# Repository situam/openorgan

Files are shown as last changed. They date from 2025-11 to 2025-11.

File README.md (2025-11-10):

# Open Organ

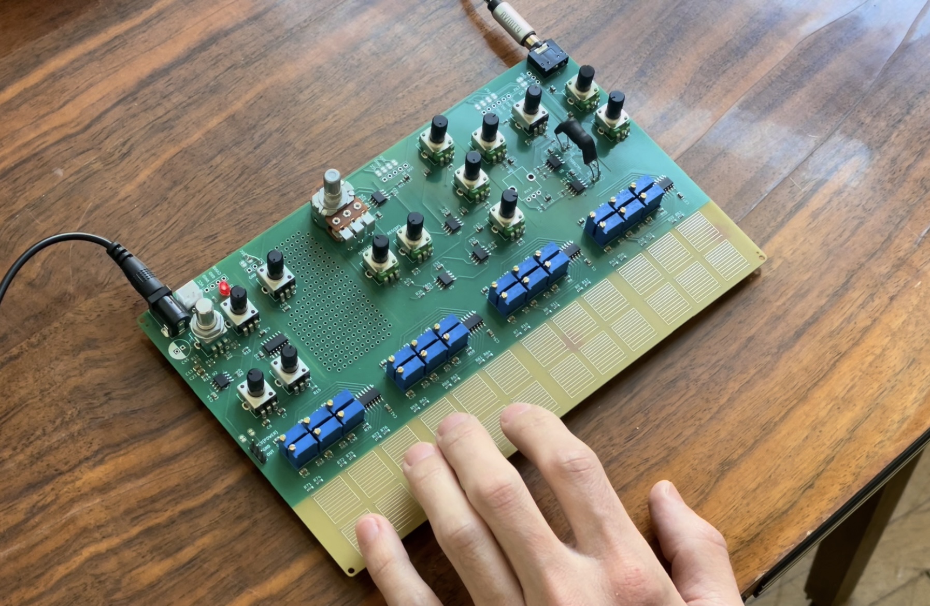
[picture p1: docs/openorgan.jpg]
open organ


A paraphonic analog synthesizer that offers tangible connections to its circuitry. Touch and moisture sensitive traces let the tunable voices flow into the shaping section. Filter, compressor, vibrato, and mixing modules are built in. Sound is also shaped by its power input, inviting musical interaction with the power source.

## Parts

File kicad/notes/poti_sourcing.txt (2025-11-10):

mouser stereo poti options
---

https://www.mouser.at/ProductDetail/Bourns/PTD902-1015K-B504?qs=%2FxQVPCMPNzj22d5HM%2FGT0Q%3D%3D

https://www.mouser.at/ProductDetail/Bourns/PDB182-K420K-504A?qs=g604JUmzuqvbczlAj9HJPA%3D%3D

https://www.mouser.at/ProductDetail/Bourns/PDB182-K420K-504A?qs=g604JUmzuqvbczlAj9HJPA%3D%3D

https://www.mouser.at/datasheet/2/54/PDB18-1013655.pdf

https://www.mouser.at/ProductDetail/Bourns/PDB182-K418F-105B?qs=2cAdsCoAWREzf3xvOlUM0Q%3D%3D

https://www.mouser.at/ProductDetail/Bourns/PDB182-D420K-503A?qs=h2IHEVivlqBUEPbrzurelQ%3D%3D

https://www.mouser.at/ProductDetail/Bourns/PDB182-D420K-503A?qs=h2IHEVivlqBUEPbrzurelQ%3D%3D

https://www.mouser.at/ProductDetail/Bourns/PDB182-K418F-105B?qs=2cAdsCoAWREzf3xvOlUM0Q%3D%3D

https://www.mouser.at/ProductDetail/Bourns/PDB182-K420K-504B?qs=g604JUmzuquwc%2Fv6HrgM%252Bg%3D%3D

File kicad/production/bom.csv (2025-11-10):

Designator | Footprint | Quantity | Value | LCSC Part #
C1, C27, C34, C41, C50, C51, C52, C53 | 0805 | 8 | 100nF
C10 | 0805 | 1 | 4.7uF
C11, C12 | 0805 | 2 | 10nF
C13, C14, C22, C24, C25 | 0805 | 5 | 0.1uF
C15, C16, C17, C18, C19, C20, C21, C23, C7, C9 | 0805 | 10 | 10uF
C2, C26, C28, C29, C3, C30, C31, C32, C33, C35, C36, C37, C38, C39, C4, C40, C42, C43, C44, C46, C47, C48, C5, C6 | 0805 | 24 | 0.47uF
C49 | 0805 | 1 | 10-100nF
C8 | 0805 | 1 | 1uF
R1, R10, R11, R12, R15, R2, R23, R24, R25, R26, R3, R4, R40, R41, R42, R43, R44, R45, R46, R47, R48, R49, R5, R50, R51, R52, R53, R54, R55, R56, R57, R58, R59, R6, R60, R61, R62, R63, R64, R65, R66, R67, R68, R69, R7, R70, R71, R72, R73, R74, R75, R76, R77, R78, R8, R9 | 0603 | 56 | 1K
R13, R14, R18, R19, R20, R27, R28, R29, R30, R34 | 0603 | 10 | 100K
R16, R17, R31, R32, R33, R37, R38, R39 | 0603 | 8 | 10K
R21 | 0603 | 1 | 47R
R22 | 0603 | 1 | 22K
R35 | 0603 | 1 | 33K
R79 | 0603 | 1 | 4.7K
RV1, RV2, RV21, RV22, RV23, RV24, RV25, RV26, RV27, RV28, RV29, RV3, RV30, RV31, RV32, RV33, RV34, RV35, RV36, RV37, RV38, RV4, RV5, RV6 | Potentiometer_Bourns_3296W_Vertical | 24 | 100K | C118963
U1, U10, U11, U12, U3 | SOIC-14_L8.7-W3.9-P1.27-LS6.0-BL | 5 | 40106 | C38184
U2 | SOIC-8_L5.0-W4.0-P1.27-LS6.0-BL | 1 | LM358 | C7950
U4, U5, U6, U7, U8, U9 | SOIC-8_L4.9-W3.9-P1.27-LS6.0-BL | 6 | NE5532 | C7426

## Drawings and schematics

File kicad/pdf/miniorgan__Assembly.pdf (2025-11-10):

A

A

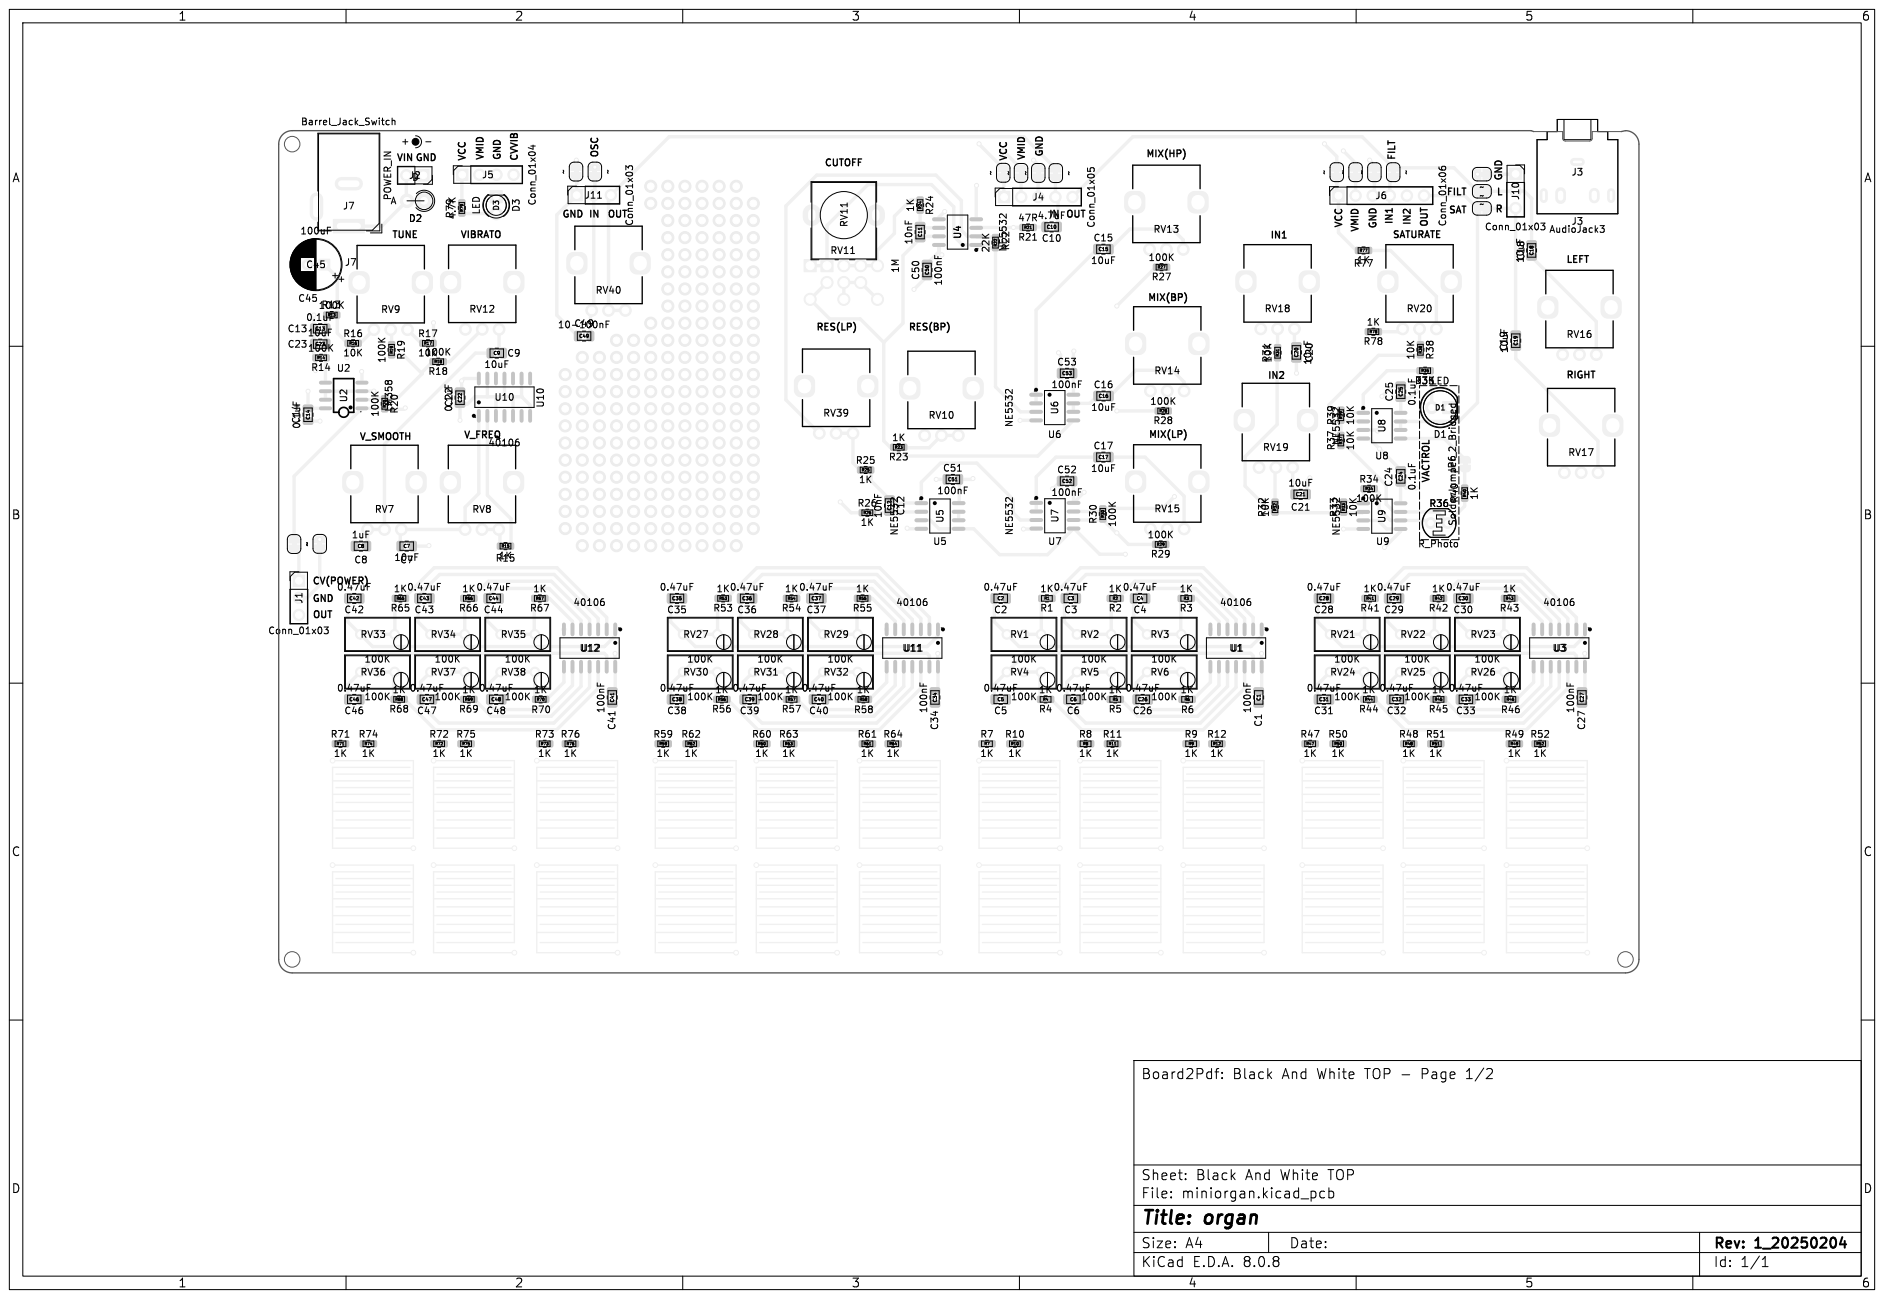
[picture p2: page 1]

File: miniorgan.kicad_pcb Sheet: Black And White TOP
Id: 1/1 Title: organ

A

A

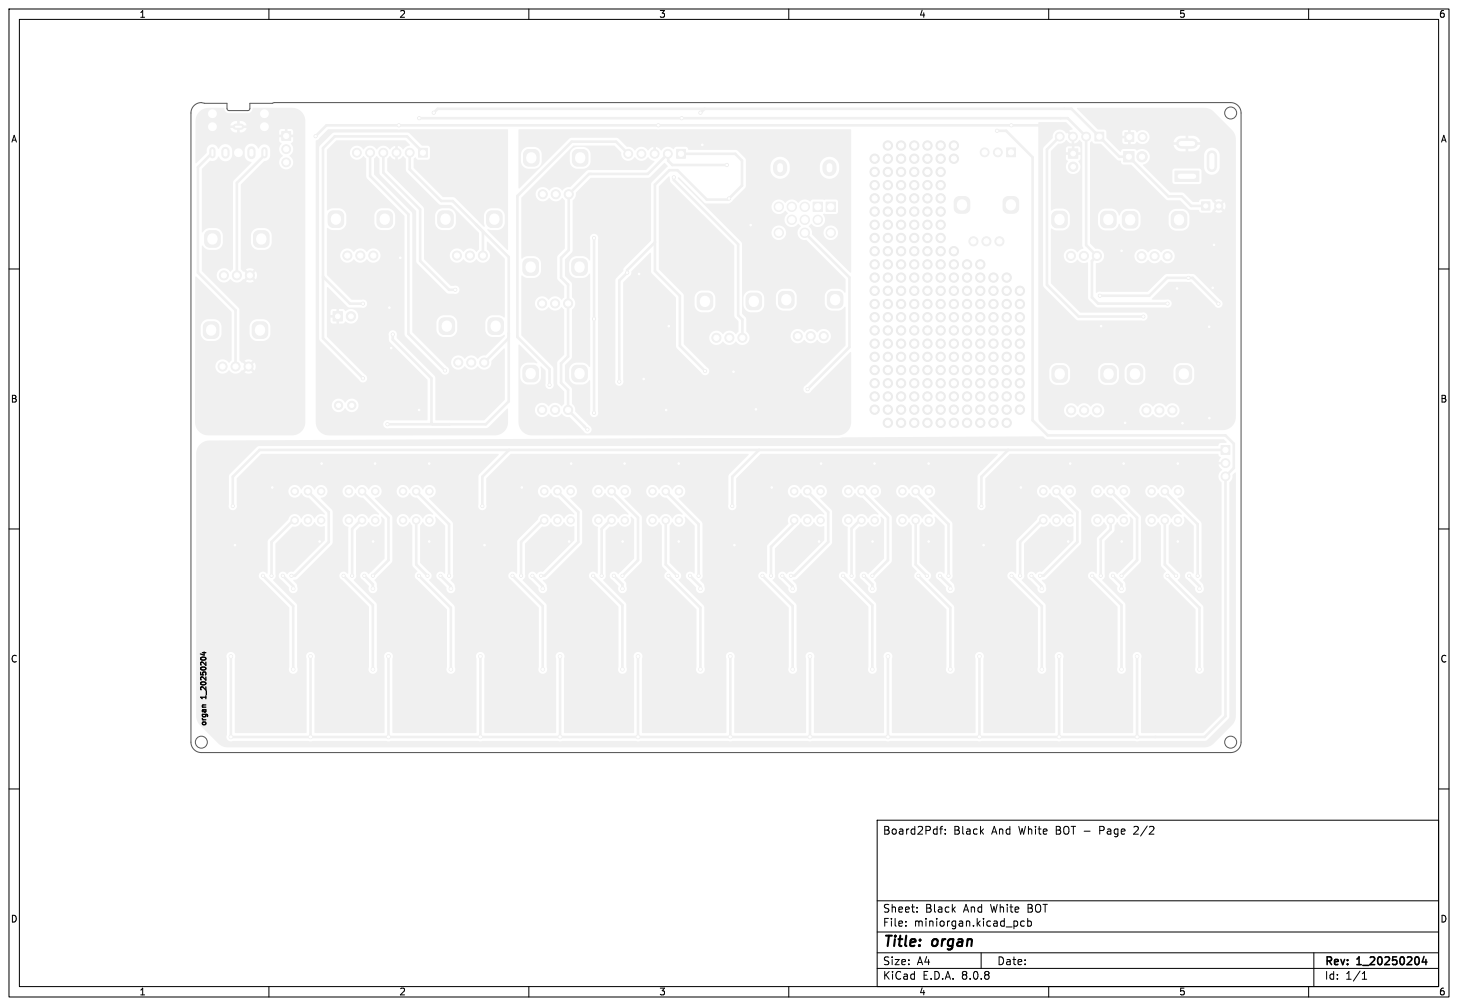
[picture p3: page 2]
organ 1_20250204 1 2 3 4 5 6; D Date: KiCad; E.D.A. 8.0.8 Size: A4; Rev: 1_20250204; File: miniorgan.kicad_pcb Sheet: Black; And; White; BOT Board2Pdf:; Black; BOT -; Page 2/2

Id: 1/1 Title: organ

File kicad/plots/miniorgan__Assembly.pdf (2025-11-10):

A

A

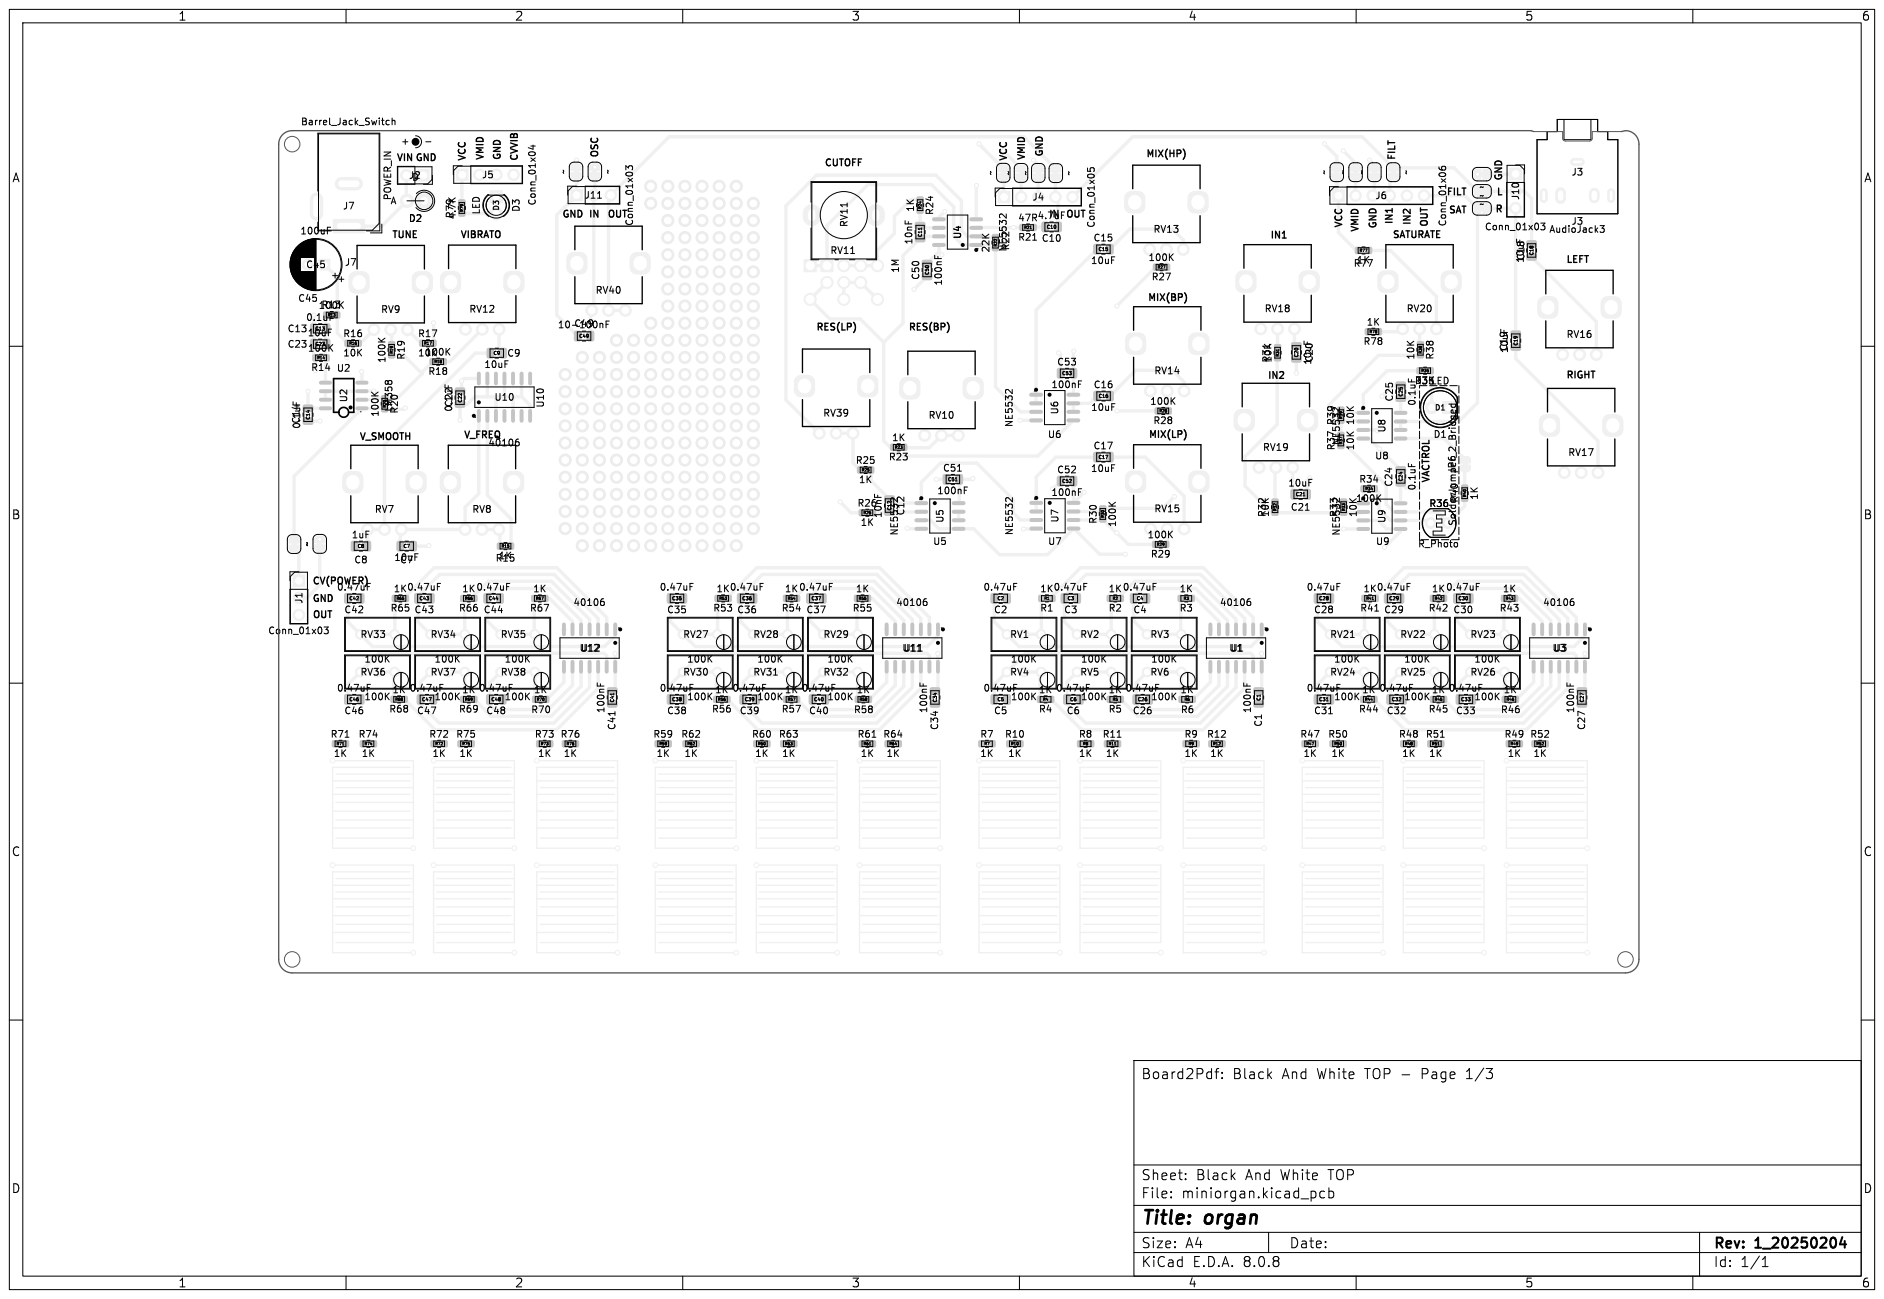
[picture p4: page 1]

File: miniorgan.kicad_pcb Sheet: Black And White TOP
Id: 1/1 Title: organ

A

A

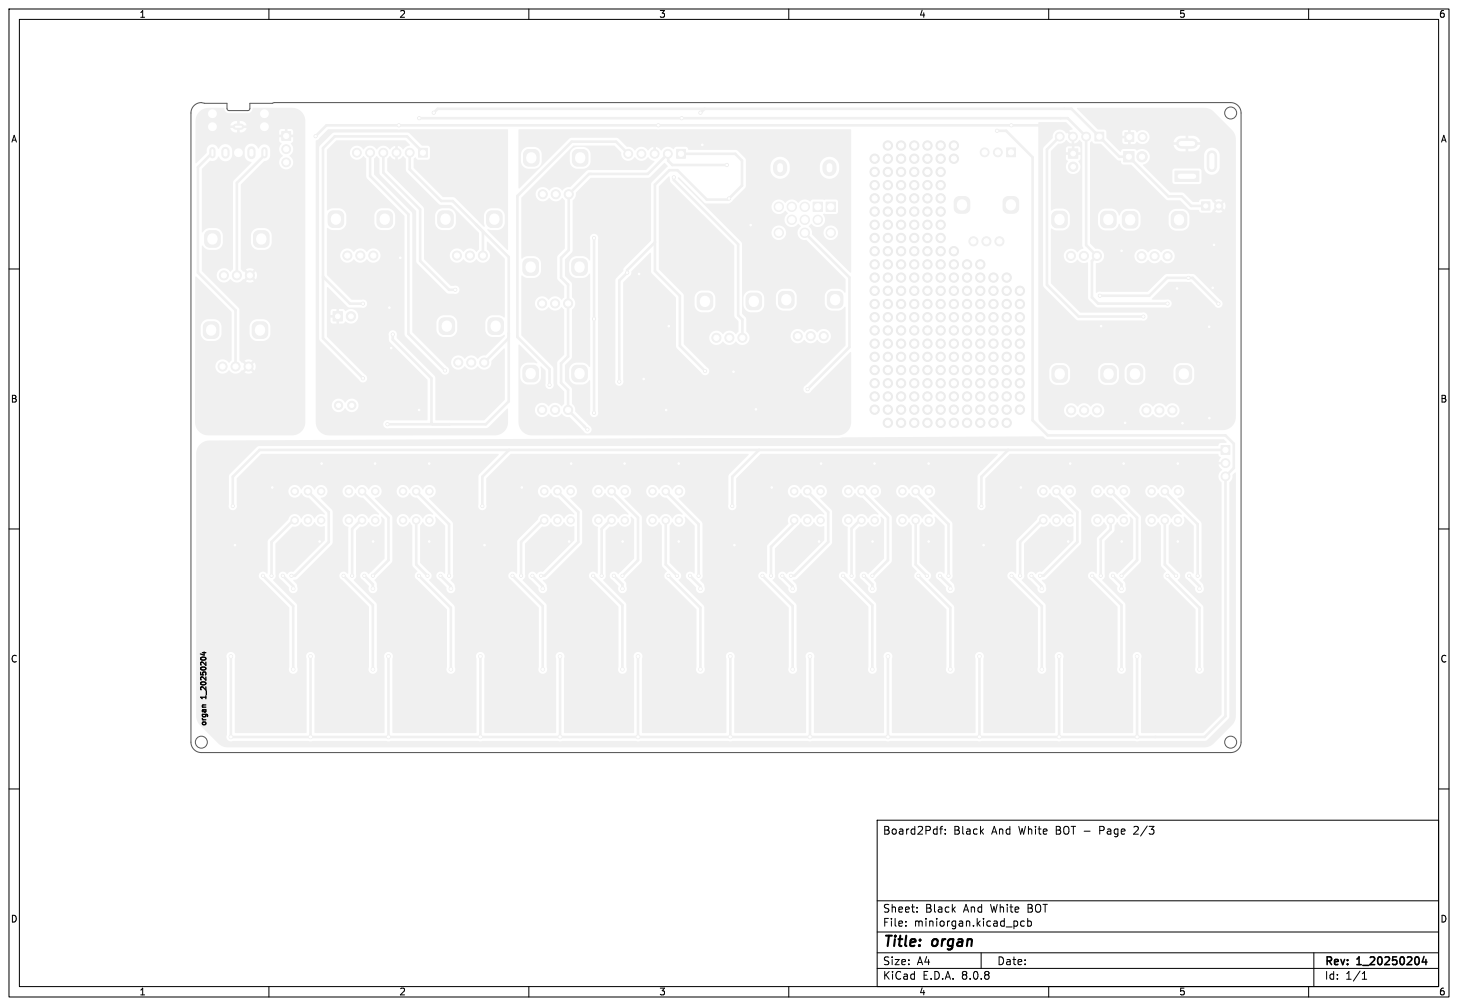
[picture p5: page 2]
organ 1_20250204 1 2 3 4 5 6; D Date: KiCad; E.D.A. 8.0.8 Size: A4; Rev: 1_20250204; File: miniorgan.kicad_pcb Sheet: Black; And; White; BOT Board2Pdf:; Black; BOT -; Page 2/3

Id: 1/1 Title: organ

A

A

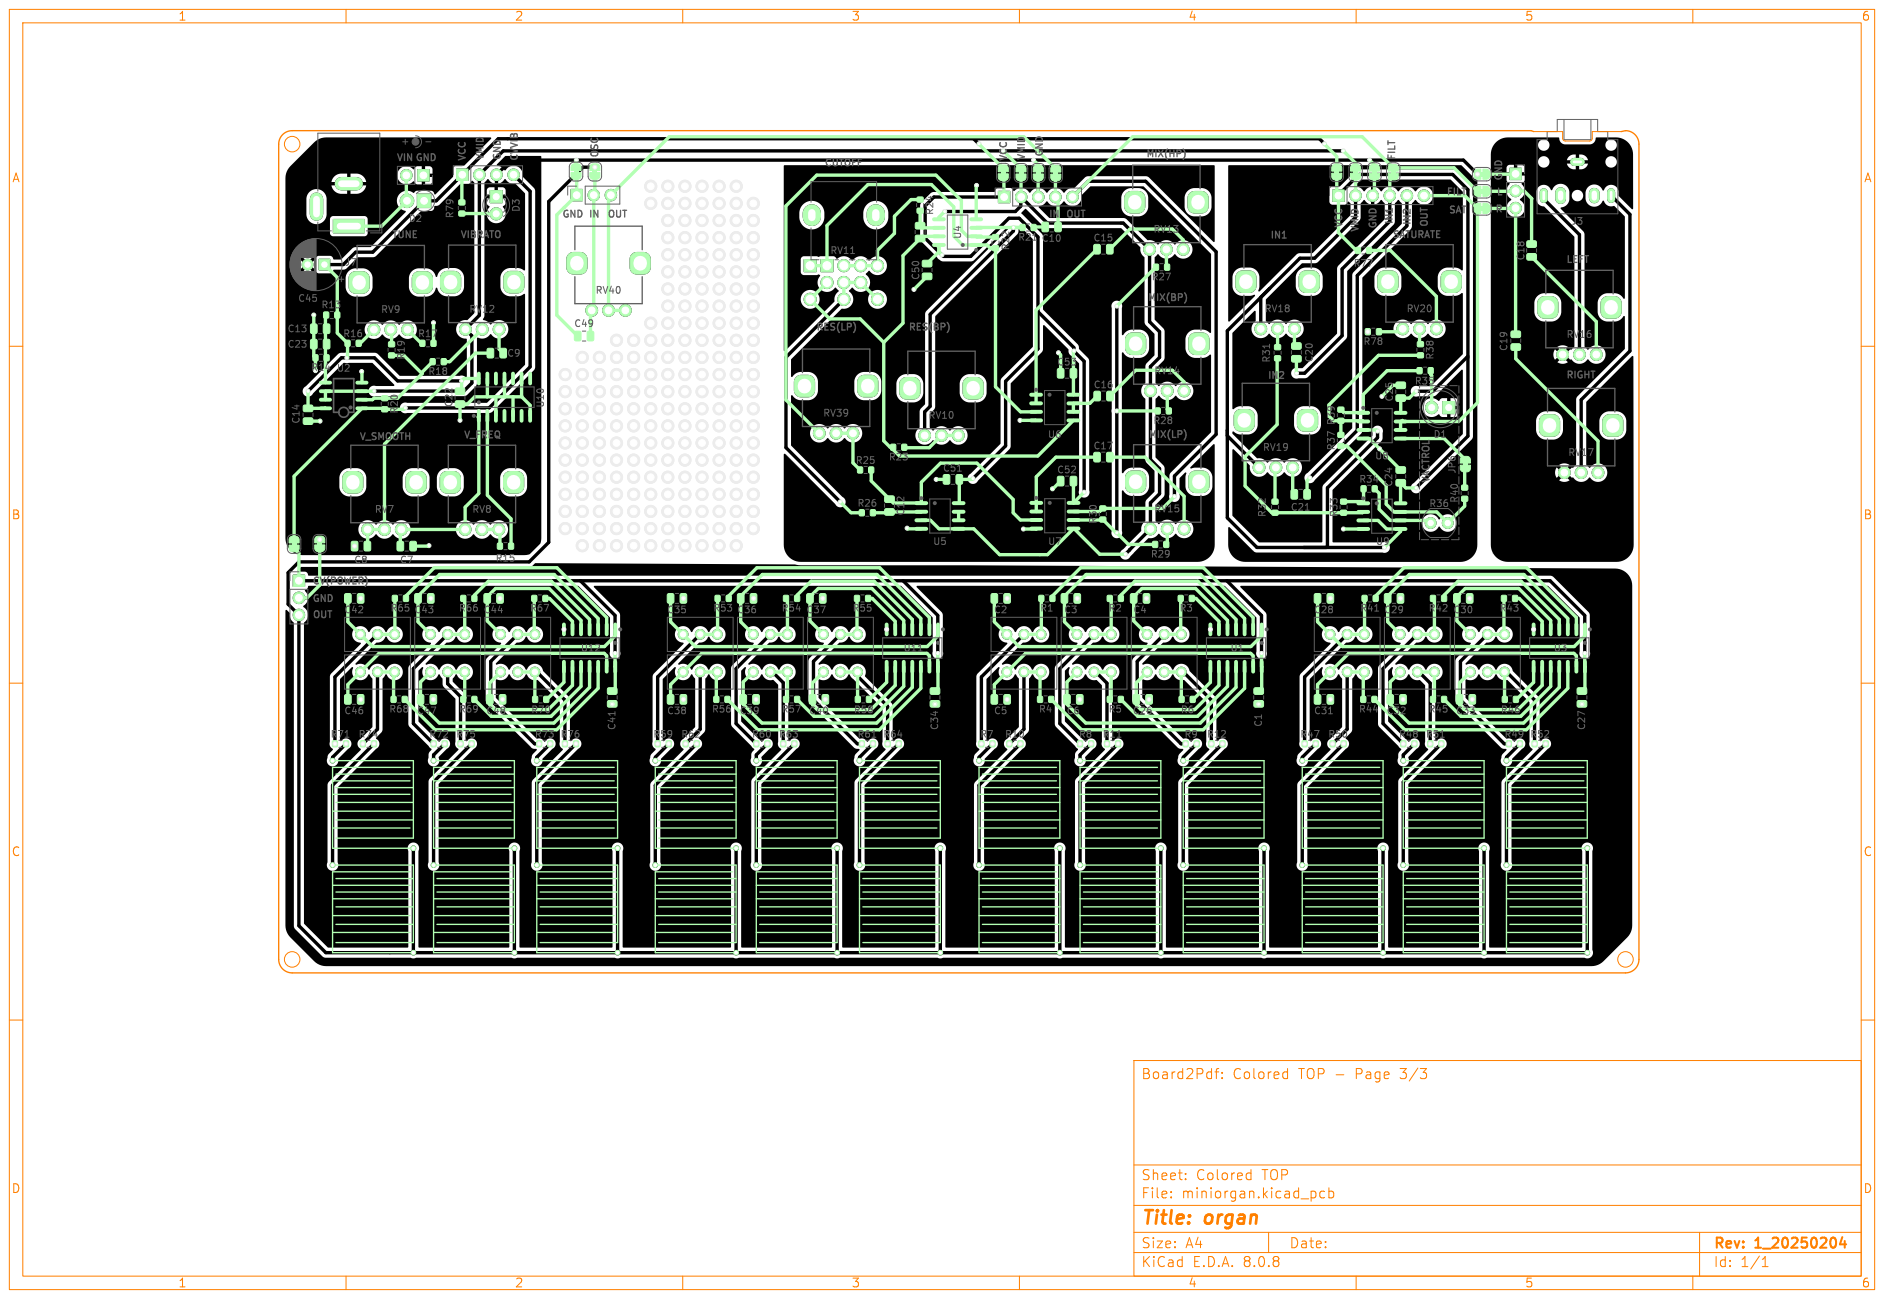
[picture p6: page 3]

File: miniorgan.kicad_pcb Sheet: Colored TOP
Id: 1/1 Title: organ

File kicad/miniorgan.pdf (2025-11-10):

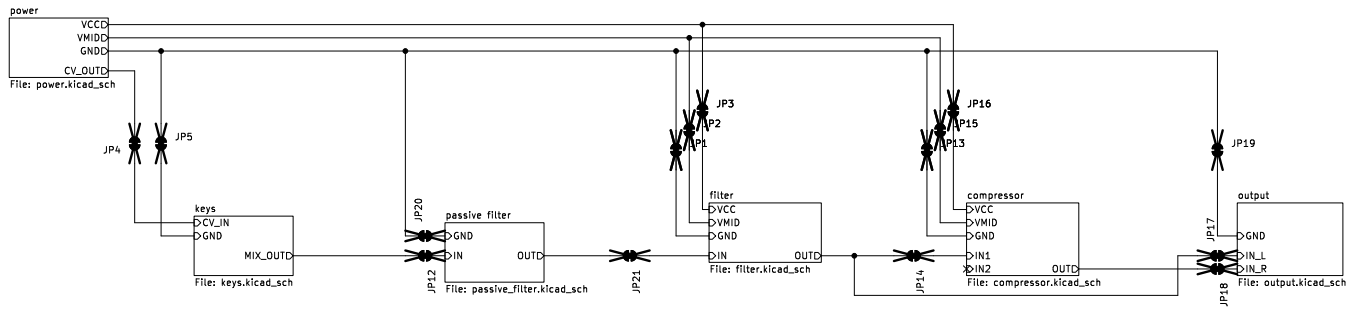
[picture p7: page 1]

VCC
CV_OUT VMID
filter File: filter.kicad_sch GND

compressor File: compressor.kicad_sch MIX_OUT GND
keys File: keys.kicad_sch

output File: output.kicad_sch VMID

File: miniorgan.kicad_sch Sheet: /
Id: 1/11 Title: Open Organ

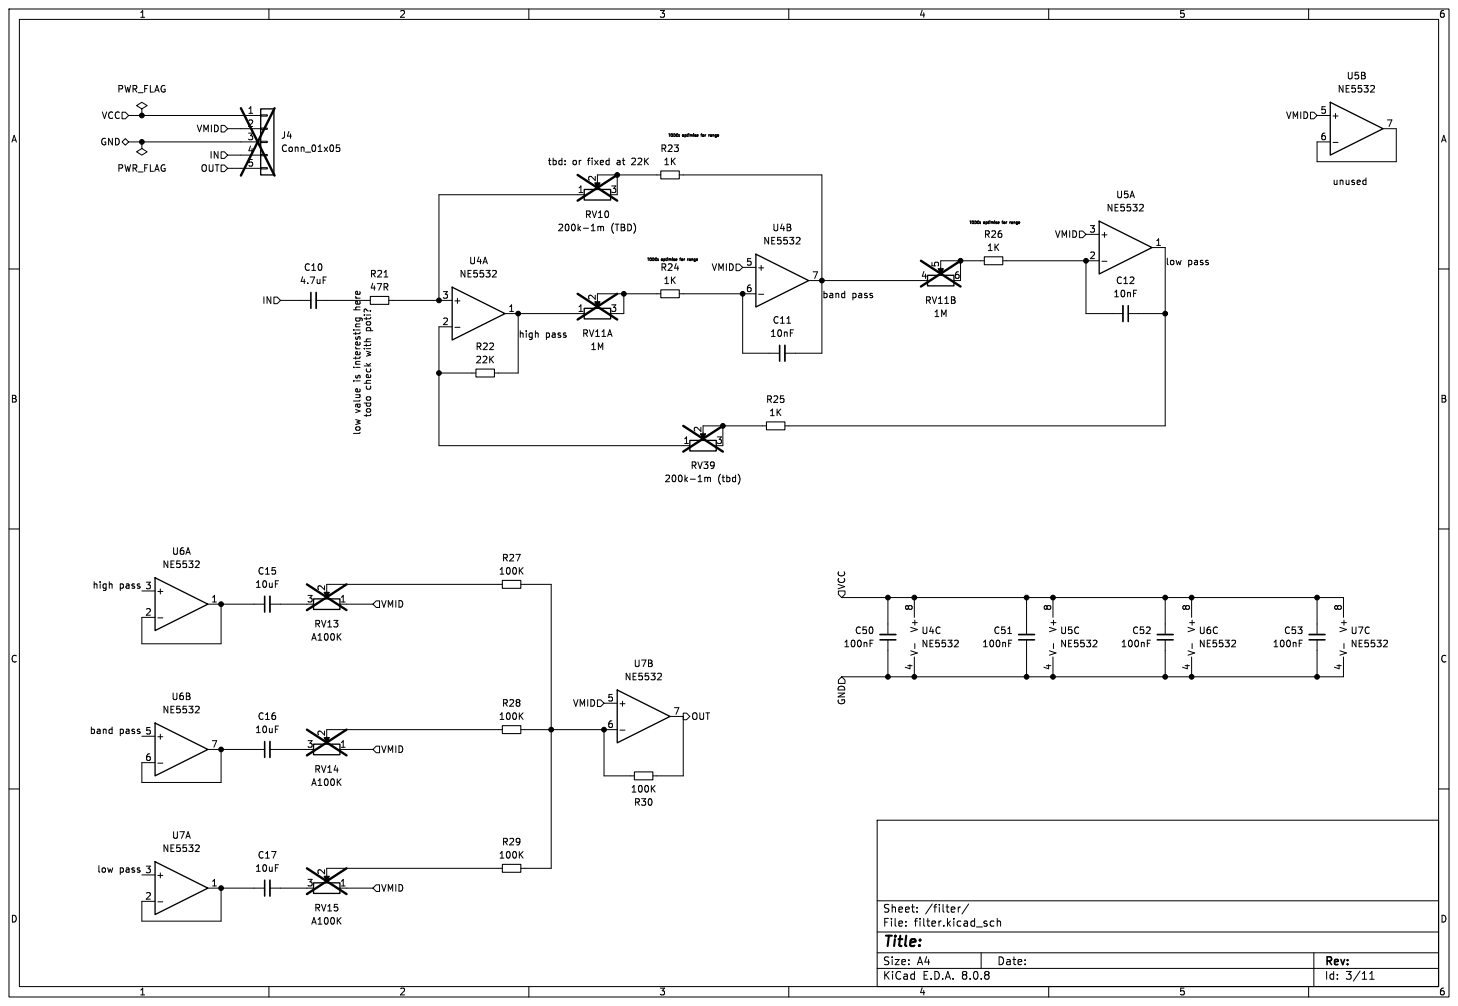
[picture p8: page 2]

Id: 3/11 Title: File: filter.kicad_sch Sheet: /filter/ +

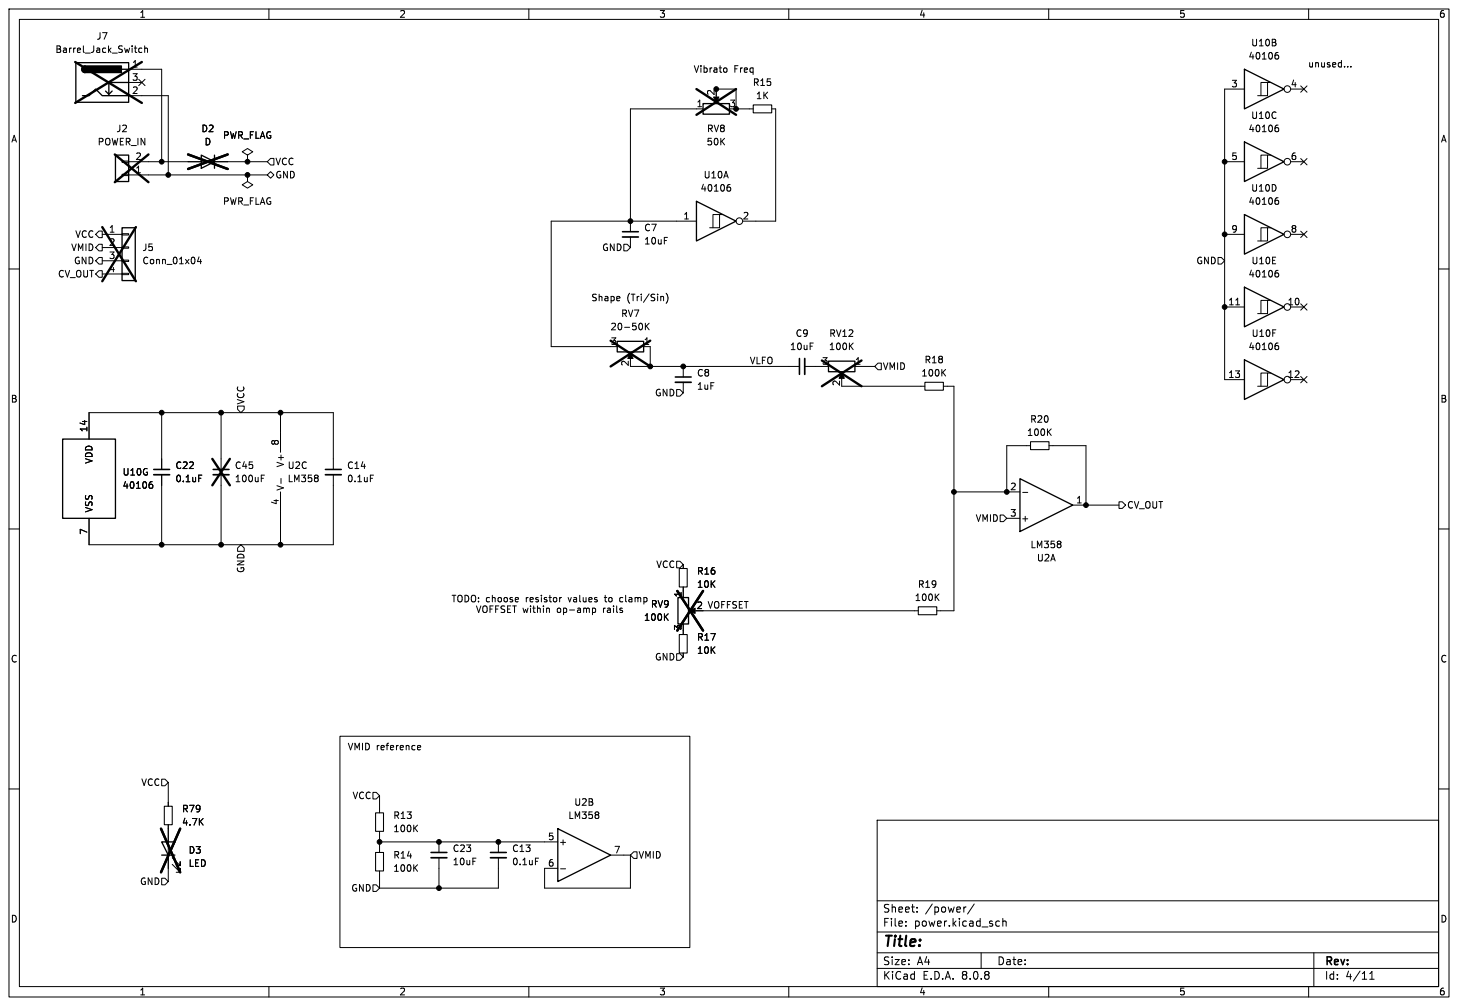
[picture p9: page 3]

Id: 4/11 Title: File: power.kicad_sch Sheet: /power/

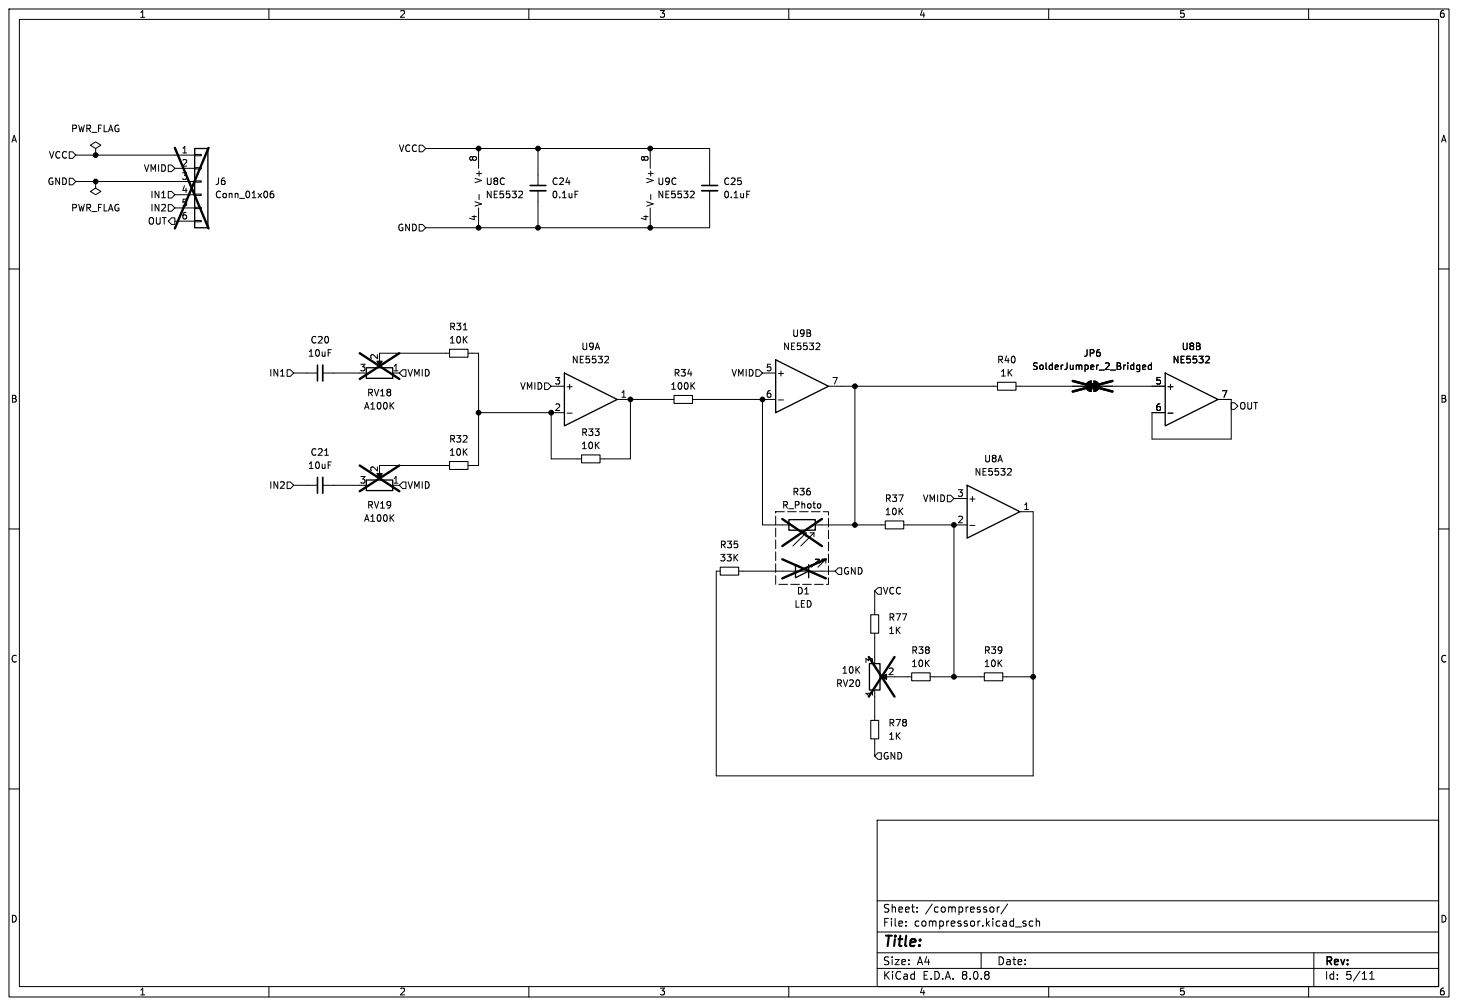
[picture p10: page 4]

Id: 5/11 Title: File: compressor.kicad_sch Sheet: /compressor/ R78

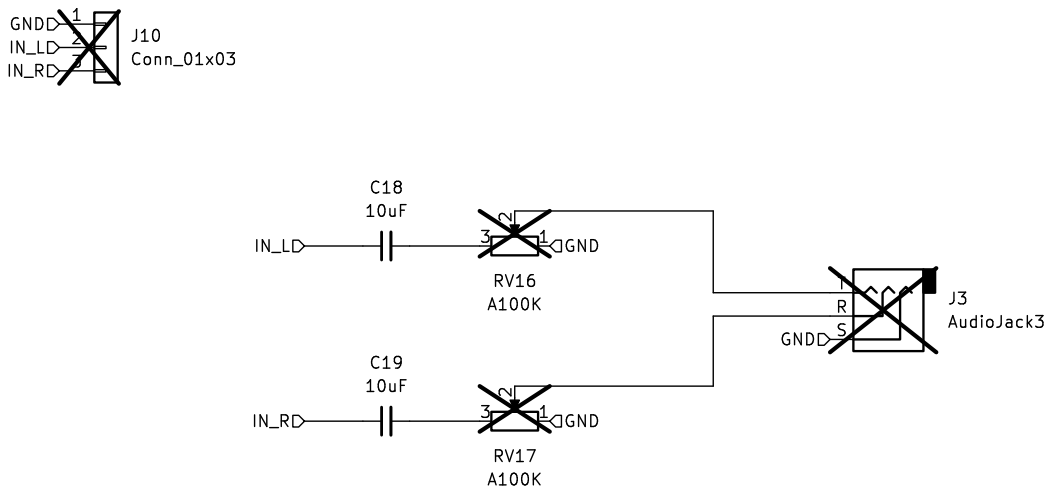
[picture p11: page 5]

Id: 7/11 Title: File: output.kicad_sch Sheet: /output/

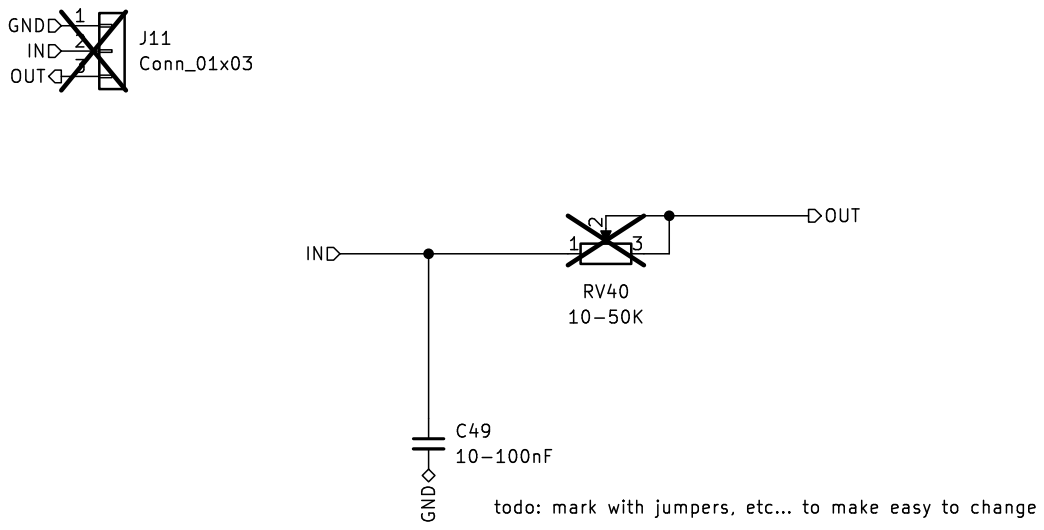
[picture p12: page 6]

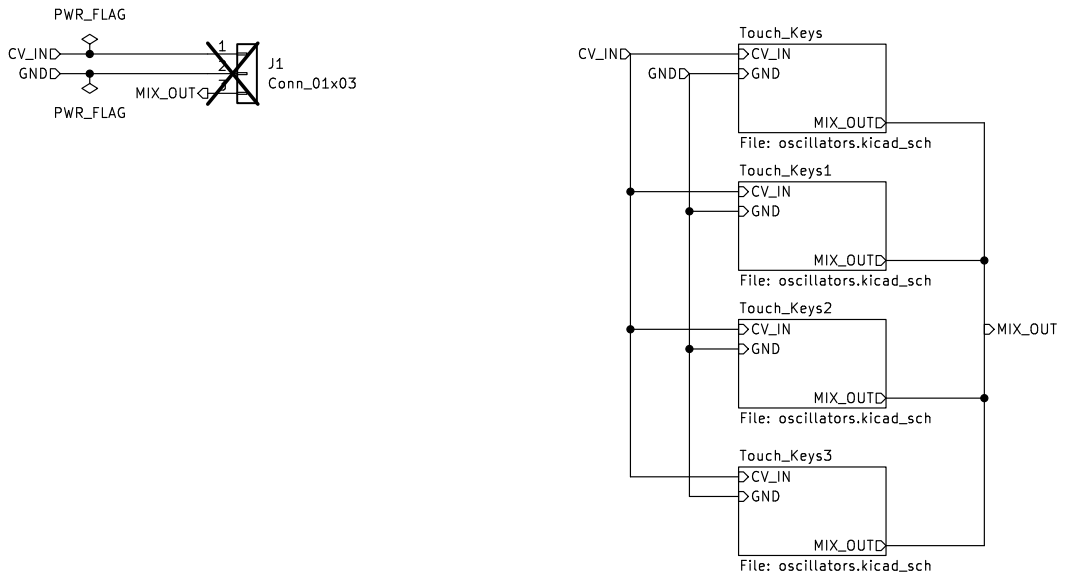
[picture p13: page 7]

Id: 11/11 Title: File: keys.kicad_sch Sheet: /keys/ MIX_OUT CV_IN GND


Id: 12/11 Title: File: oscillators.kicad_sch Sheet: /keys/Touch_Keys/ R6


Id: 13/11 Title: File: oscillators.kicad_sch Sheet: /keys/Touch_Keys1/ R46


Id: 14/11 Title: File: oscillators.kicad_sch Sheet: /keys/Touch_Keys2/ R58


Id: 15/11 Title: File: oscillators.kicad_sch Sheet: /keys/Touch_Keys3/ R70

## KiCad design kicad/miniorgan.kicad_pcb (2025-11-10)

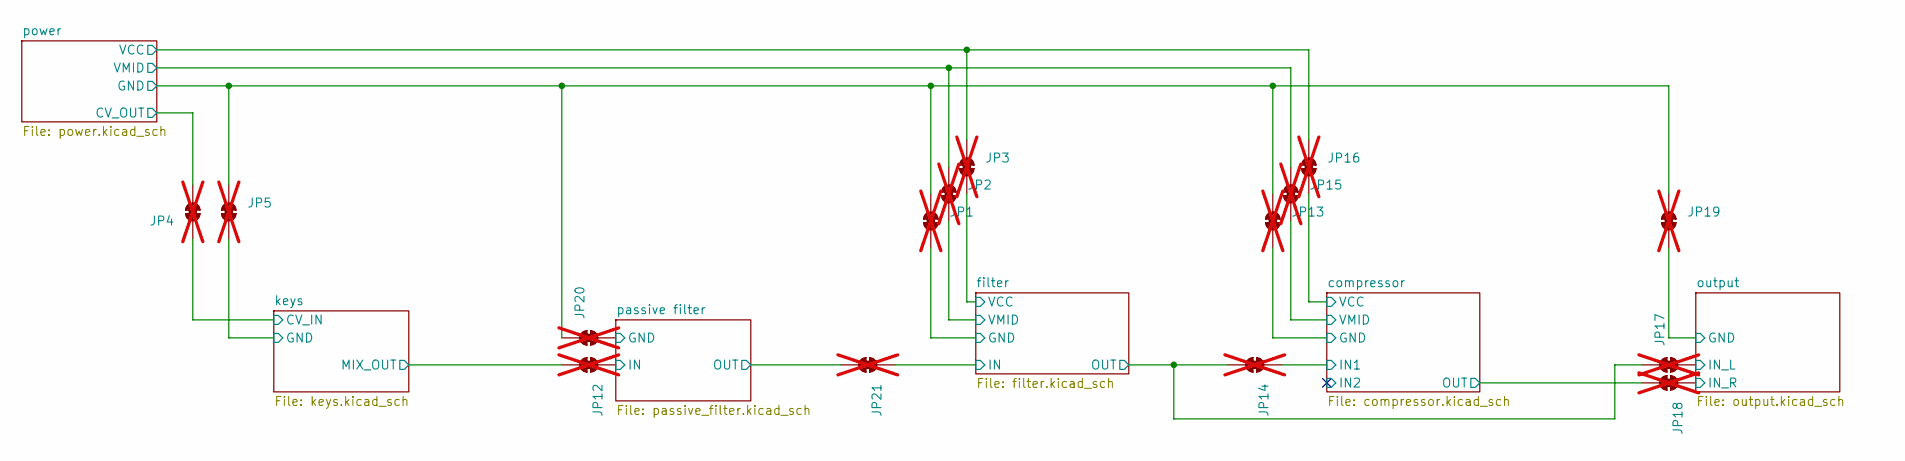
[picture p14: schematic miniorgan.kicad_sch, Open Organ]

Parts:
JP1, JP2, JP3, JP4, JP5, JP12, JP13, JP14, JP15, JP16, JP17, JP18, JP19, JP20, JP21: SolderJumper-2_P1.3mm_Bridged_RoundedPad1.0x1.5mm; not fitted

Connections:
/Filter/GND: JP1.2 (B); also elsewhere on the board
/Filter/IN: JP21.1 (A); also elsewhere on the board
/Filter/OUT: JP14.2 (B), JP17.1 (A); also elsewhere on the board
/Filter/VCC: JP3.2 (B); also elsewhere on the board
/Filter/VMID: JP2.2 (B); also elsewhere on the board
/keys/CV_IN: JP4.1 (A); also elsewhere on the board
/keys/GND: JP5.2 (B); also elsewhere on the board
/keys/MIX_OUT: JP12.2 (B); also elsewhere on the board
/output/GND: JP19.2 (B); also elsewhere on the board
/output/IN_L: JP17.2 (B); also elsewhere on the board
/output/IN_R: JP18.1 (A); also elsewhere on the board
/passive filter/GND: JP20.2 (B); also elsewhere on the board
/passive filter/IN: JP12.1 (A); also elsewhere on the board
/passive filter/OUT: JP21.2 (B); also elsewhere on the board
/power/CV_OUT: JP4.2 (B); also elsewhere on the board
/power/GND: JP1.1 (A), JP5.1 (A), JP13.1 (A), JP19.1 (A), JP20.1 (A); also elsewhere on the board
/power/VCC: JP3.1 (A), JP16.1 (A); also elsewhere on the board
/power/VMID: JP2.1 (A), JP15.1 (A); also elsewhere on the board
/vactrol compressor/GND: JP13.2 (B); also elsewhere on the board
/vactrol compressor/IN1: JP14.1 (A); also elsewhere on the board
/vactrol compressor/OUT: JP18.2 (B); also elsewhere on the board
/vactrol compressor/VCC: JP16.2 (B); also elsewhere on the board
/vactrol compressor/VMID: JP15.2 (B); also elsewhere on the board

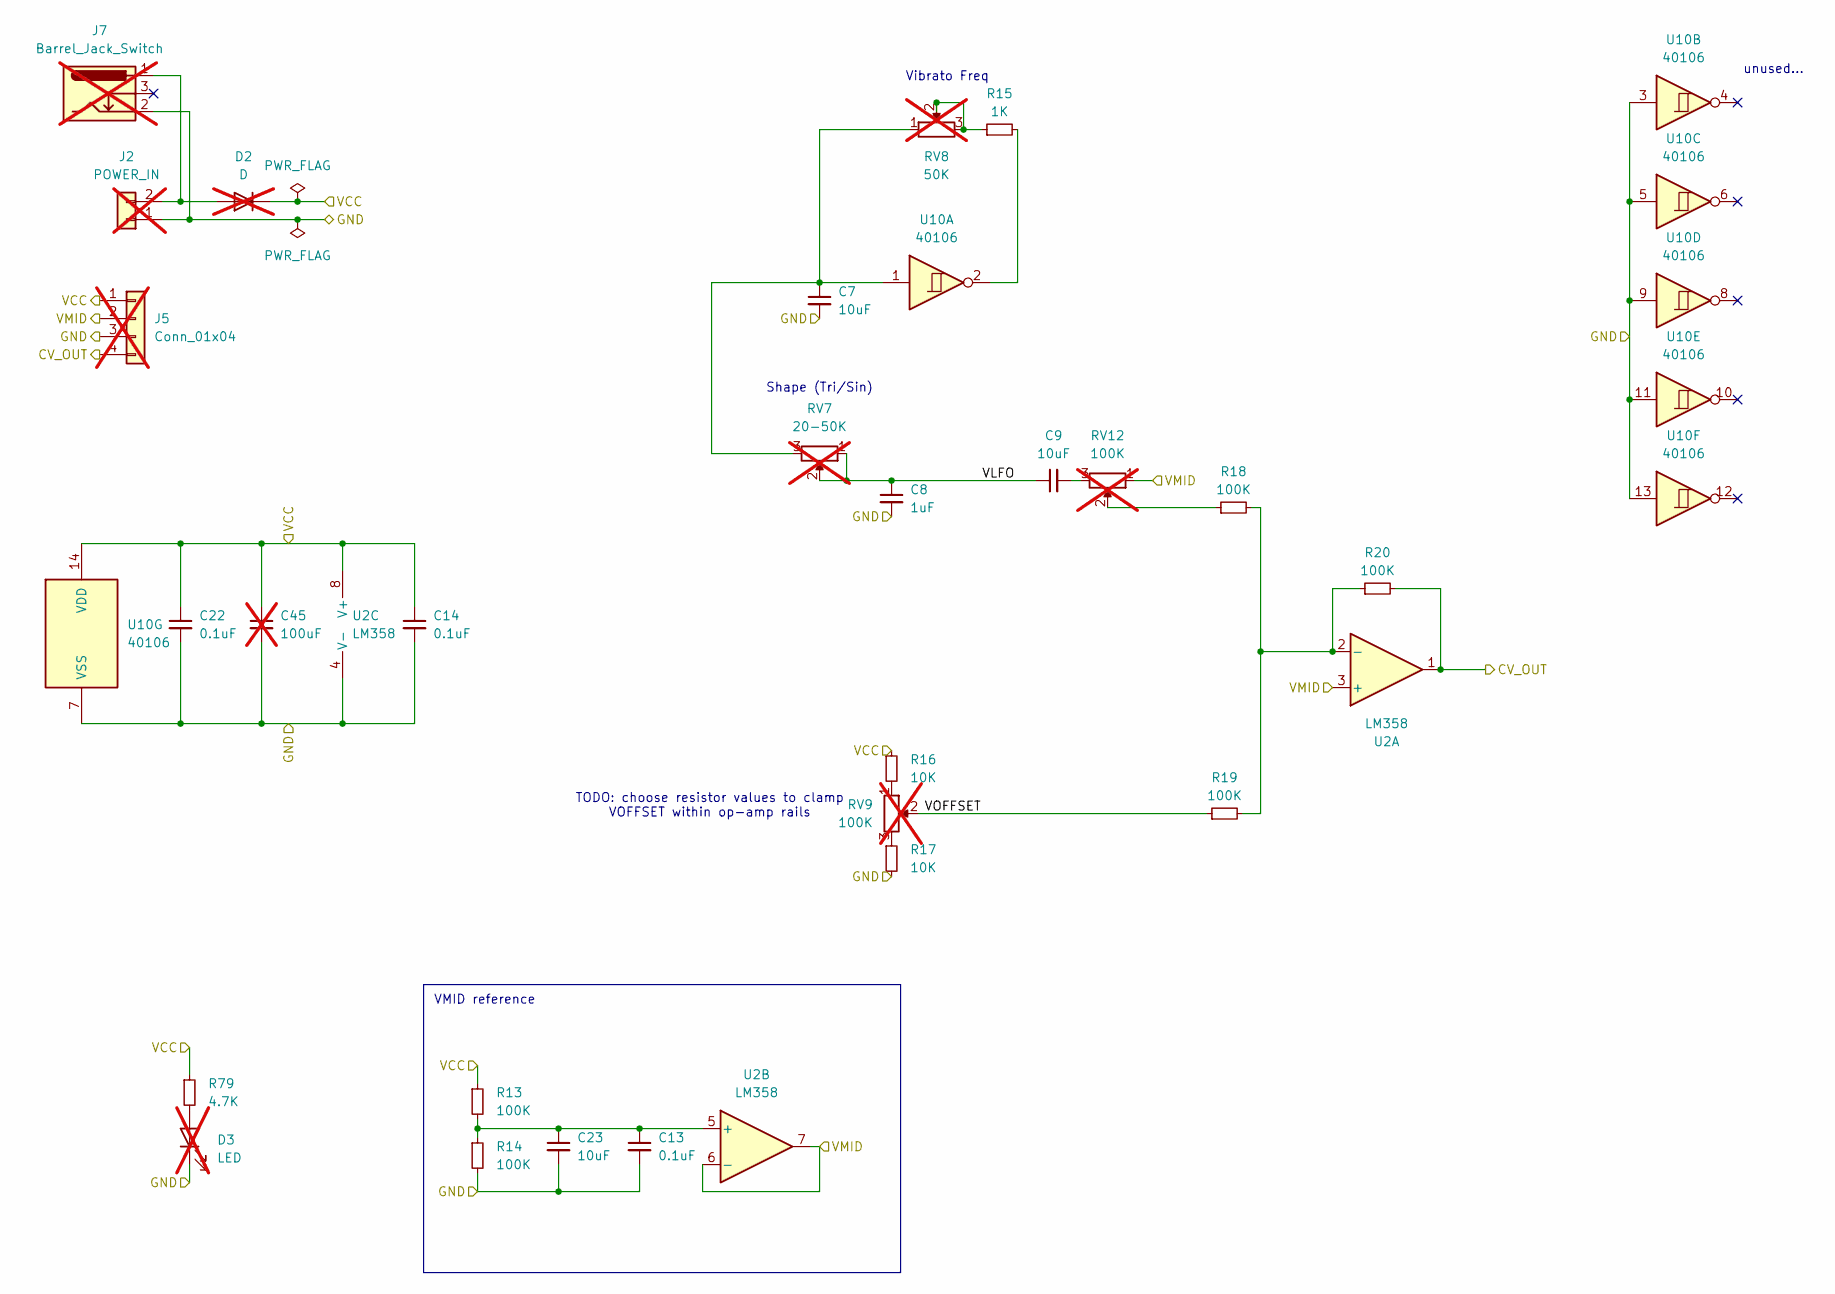
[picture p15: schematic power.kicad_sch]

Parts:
C7, C9, C23: 10uF; C_0805_2012Metric
C8: 1uF; C_0805_2012Metric
C13, C14, C22: 0.1uF; C_0805_2012Metric
C45: 100uF; CP_Radial_D7.5mm_P2.50mm; not fitted
D2: D; D_T-1_P2.54mm_Vertical_AnodeUp; not fitted
D3: LED; LED_D3.0mm; not fitted
J2: POWER_IN; PinSocket_1x02_P2.54mm_Vertical; not fitted
J5: Conn_01x04; PinSocket_1x04_P2.54mm_Vertical; not fitted
J7: Barrel_Jack_Switch; BarrelJack_GCT_DCJ200-10-A_Horizontal; not fitted
R13, R14, R18, R19, R20: 100K; R_0603_1608Metric
R15: 1K; R_0603_1608Metric
R16, R17: 10K; R_0603_1608Metric
R79: 4.7K; R_0603_1608Metric
RV7: 20-50K; Pot_RV09AF-ALPHA; not fitted
RV8: 50K; Pot_RV09AF-ALPHA; not fitted
RV9, RV12: 100K; Pot_RV09AF-ALPHA; not fitted
U2: LM358; SOIC-8_L5.0-W4.0-P1.27-LS6.0-BL; JLC C7950
U10: 40106; SOIC-14_L8.7-W3.9-P1.27-LS6.0-BL; JLC C38184

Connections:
/power/CV_OUT: J5.4, R20.2, U2.1; also elsewhere on the board
/power/GND: C7.2, C8.2, C13.2, C14.2, C22.2, C23.2, C45.2, D3.1 (K), J2.1, J5.3, J7.2, R14.2, R17.2, U2.4 (V-), U10.3, U10.5, U10.7 (VSS), U10.9, U10.11, U10.13; also elsewhere on the board
/power/VCC: C14.1, C22.1, C45.1, D2.1 (K), J5.1, R13.1, R16.1, R79.1, U2.8 (V+), U10.14 (VDD); also elsewhere on the board
/power/VLFO: C8.1, C9.1, RV7.1, RV7.2
/power/VMID: J5.2, RV12.1, U2.3 (+), U2.6 (-), U2.7; also elsewhere on the board
/power/VOFFSET: R19.1, RV9.2
unnamed: C7.1, RV7.3, RV8.1, U10.1
unnamed: C9.2, RV12.3
unnamed: D2.2 (A), J2.2, J7.1
unnamed: D3.2 (A), R79.2
unnamed: R15.1, RV8.2, RV8.3
unnamed: R15.2, U10.2
unnamed: R16.2, RV9.1
unnamed: R17.1, RV9.3
unnamed: R18.1, RV12.2
unnamed: R18.2, R19.2, R20.1, U2.2 (-)
unnamed: C13.1, C23.1, R13.2, R14.1, U2.5 (+)

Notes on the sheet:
TODO: choose resistor values to clamp VOFFSET within op-amp rails
Vibrato Freq
Shape (Tri/Sin)
VMID reference
unused...

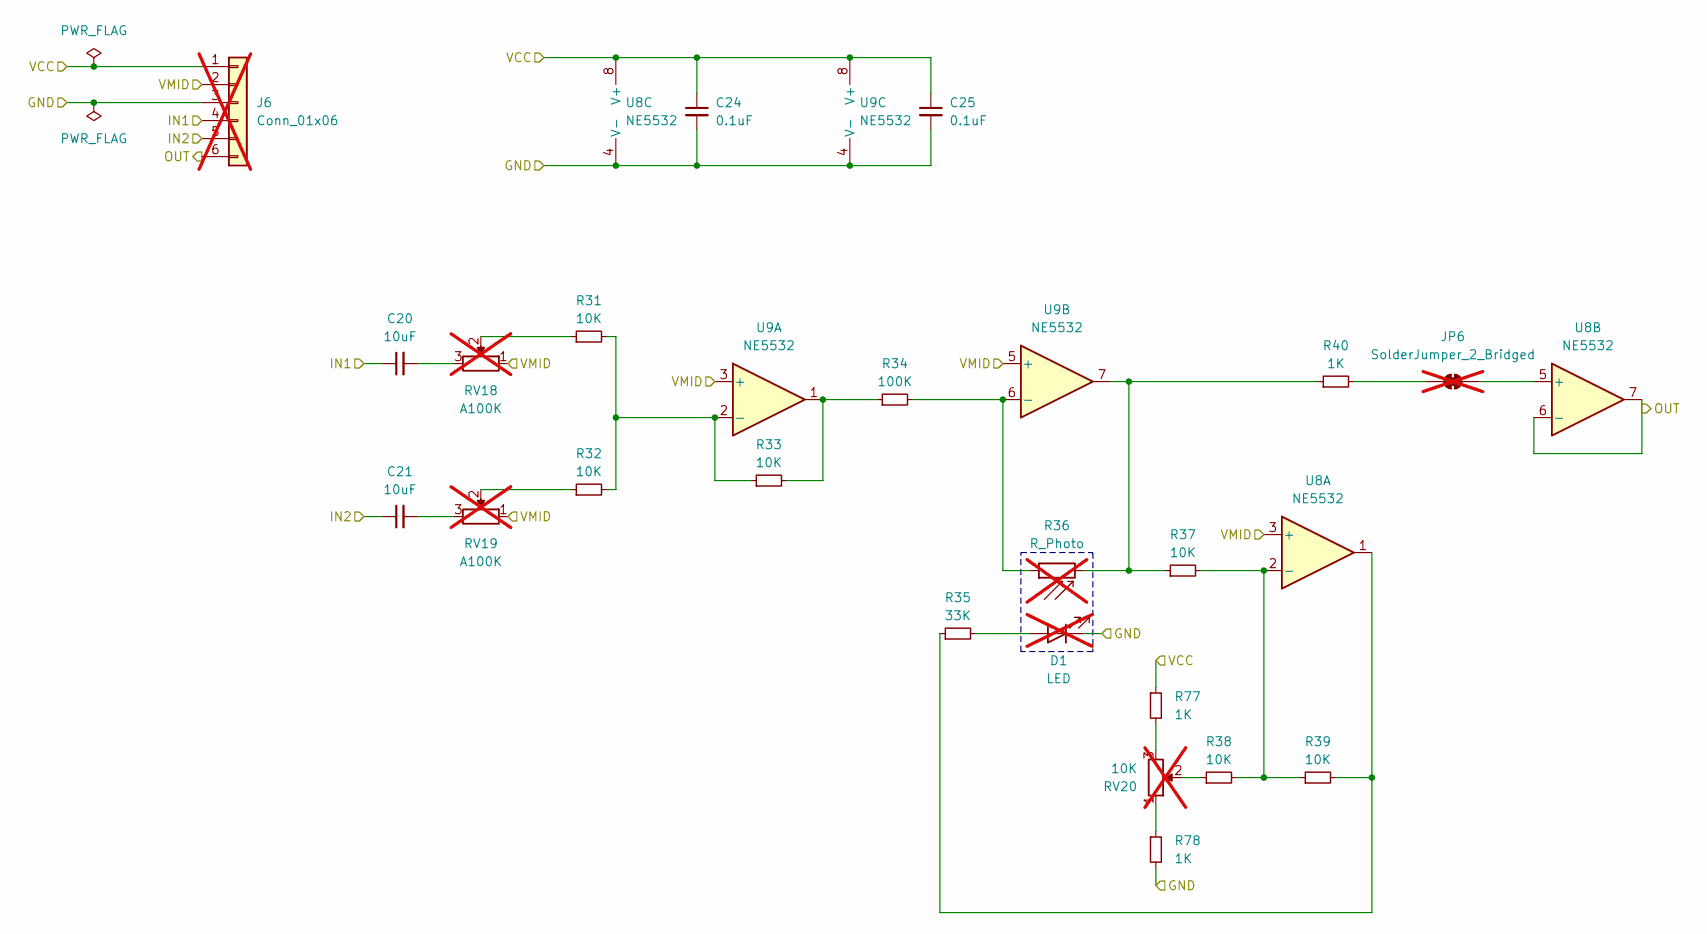
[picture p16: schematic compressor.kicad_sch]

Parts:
C20, C21: 10uF; C_0805_2012Metric
C24, C25: 0.1uF; C_0805_2012Metric
D1: LED; LED_D5.0mm_Clear; not fitted
J6: Conn_01x06; PinSocket_1x06_P2.54mm_Vertical; not fitted
JP6: SolderJumper_2_Bridged; SolderJumper-2_P1.3mm_Bridged_RoundedPad1.0x1.5mm; not fitted
R31, R32, R33, R37, R38, R39: 10K; R_0603_1608Metric
R34: 100K; R_0603_1608Metric
R35: 33K; R_0603_1608Metric
R36: R_Photo; R_LDR_4.9x4.2mm_P2.54mm_Vertical; not fitted
R40, R77, R78: 1K; R_0603_1608Metric
RV18, RV19: A100K; Pot_RV09AF-ALPHA; not fitted
RV20: 10K; Pot_RV09AF-ALPHA; not fitted
U8, U9: NE5532; SOIC-8_L4.9-W3.9-P1.27-LS6.0-BL; JLC C7426

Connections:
/vactrol compressor/GND: C24.2, C25.2, D1.1 (K), J6.3, R78.2, U8.4 (V-), U9.4 (V-); also elsewhere on the board
/vactrol compressor/IN1: C20.1, J6.4; also elsewhere on the board
/vactrol compressor/IN2: C21.1, J6.5
/vactrol compressor/OUT: J6.6, U8.6 (-), U8.7; also elsewhere on the board
/vactrol compressor/VCC: C24.1, C25.1, J6.1, R77.1, U8.8 (V+), U9.8 (V+); also elsewhere on the board
/vactrol compressor/VMID: J6.2, RV18.1, RV19.1, U8.3 (+), U9.3 (+), U9.5 (+); also elsewhere on the board
unnamed: C20.2, RV18.3
unnamed: C21.2, RV19.3
unnamed: D1.2 (A), R35.2
unnamed: JP6.1 (A), U8.5 (+)
unnamed: JP6.2 (B), R40.2
unnamed: R31.1, RV18.2
unnamed: R32.1, RV19.2
unnamed: R33.2, R34.1, U9.1
unnamed: R35.1, R39.2, U8.1
unnamed: R36.2, R37.1, R40.1, U9.7
unnamed: R38.1, RV20.2
unnamed: R77.2, RV20.3
unnamed: R78.1, RV20.1
unnamed: R37.2, R38.2, R39.1, U8.2 (-)
unnamed: R31.2, R32.2, R33.1, U9.2 (-)
unnamed: R34.2, R36.1, U9.6 (-)

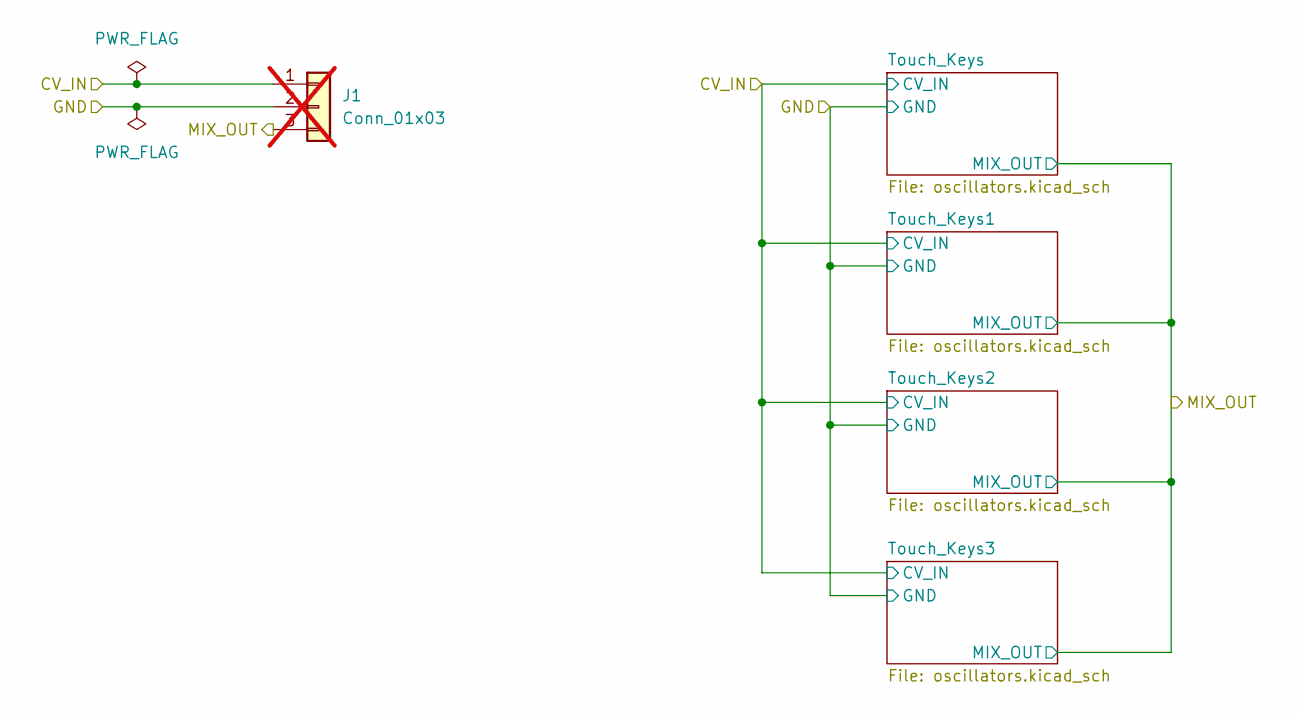
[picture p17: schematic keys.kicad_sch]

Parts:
J1: Conn_01x03; PinHeader_1x03_P2.54mm_Vertical; not fitted

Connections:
/keys/CV_IN: J1.1; also elsewhere on the board
/keys/GND: J1.2; also elsewhere on the board
/keys/MIX_OUT: J1.3; also elsewhere on the board

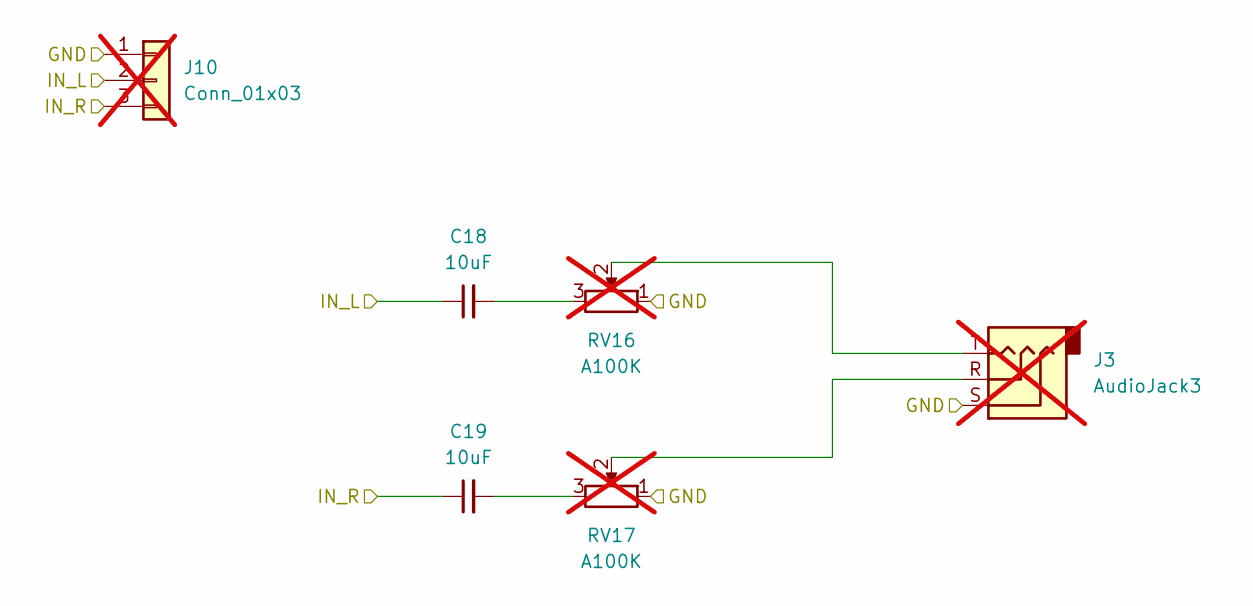
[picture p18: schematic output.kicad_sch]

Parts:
C18, C19: 10uF; C_0805_2012Metric
J3: AudioJack3; Jack_3.5mm_CUI_SJ1-3525N_Horizontal; not fitted
J10: Conn_01x03; PinSocket_1x03_P2.54mm_Vertical; not fitted
RV16, RV17: A100K; Pot_RV09AF-ALPHA; not fitted

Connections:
/output/GND: J3.S, J10.1, RV16.1, RV17.1; also elsewhere on the board
/output/IN_L: C18.1, J10.2; also elsewhere on the board
/output/IN_R: C19.1, J10.3; also elsewhere on the board
unnamed: C18.2, RV16.3
unnamed: C19.2, RV17.3
unnamed: J3.R, RV17.2
unnamed: J3.T, RV16.2

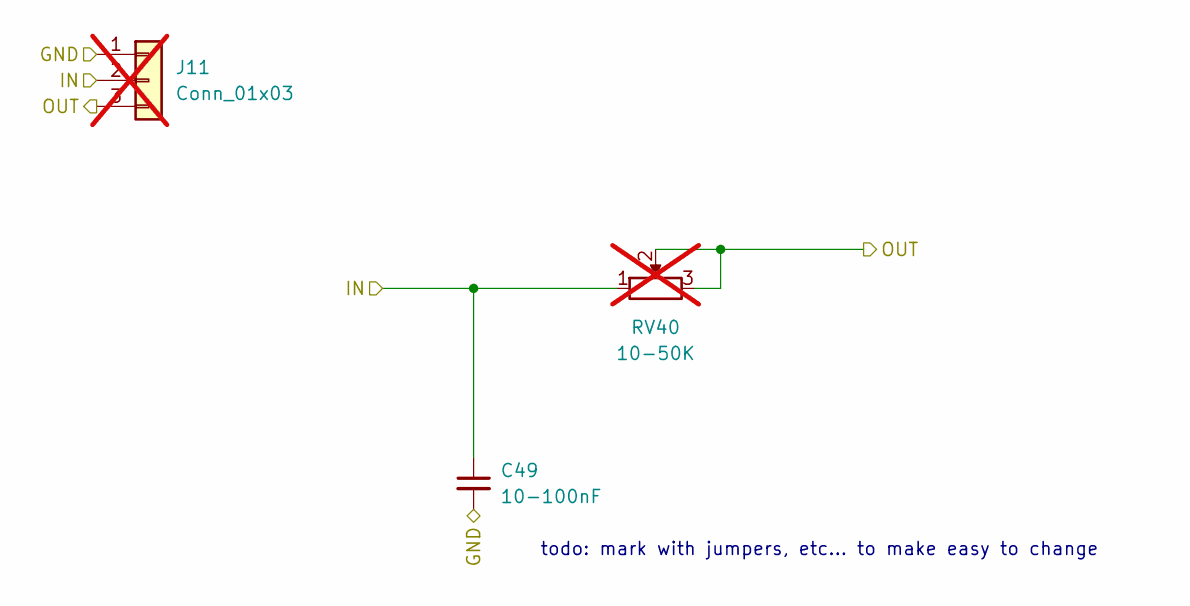
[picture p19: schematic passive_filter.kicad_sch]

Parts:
C49: 10-100nF; C_0805_2012Metric
J11: Conn_01x03; PinSocket_1x03_P2.54mm_Vertical; not fitted
RV40: 10-50K; Pot_RV09AF-ALPHA; not fitted

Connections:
/passive filter/GND: C49.2, J11.1; also elsewhere on the board
/passive filter/IN: C49.1, J11.2, RV40.1; also elsewhere on the board
/passive filter/OUT: J11.3, RV40.2, RV40.3; also elsewhere on the board

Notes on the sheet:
todo: mark with jumpers, etc... to make easy to change

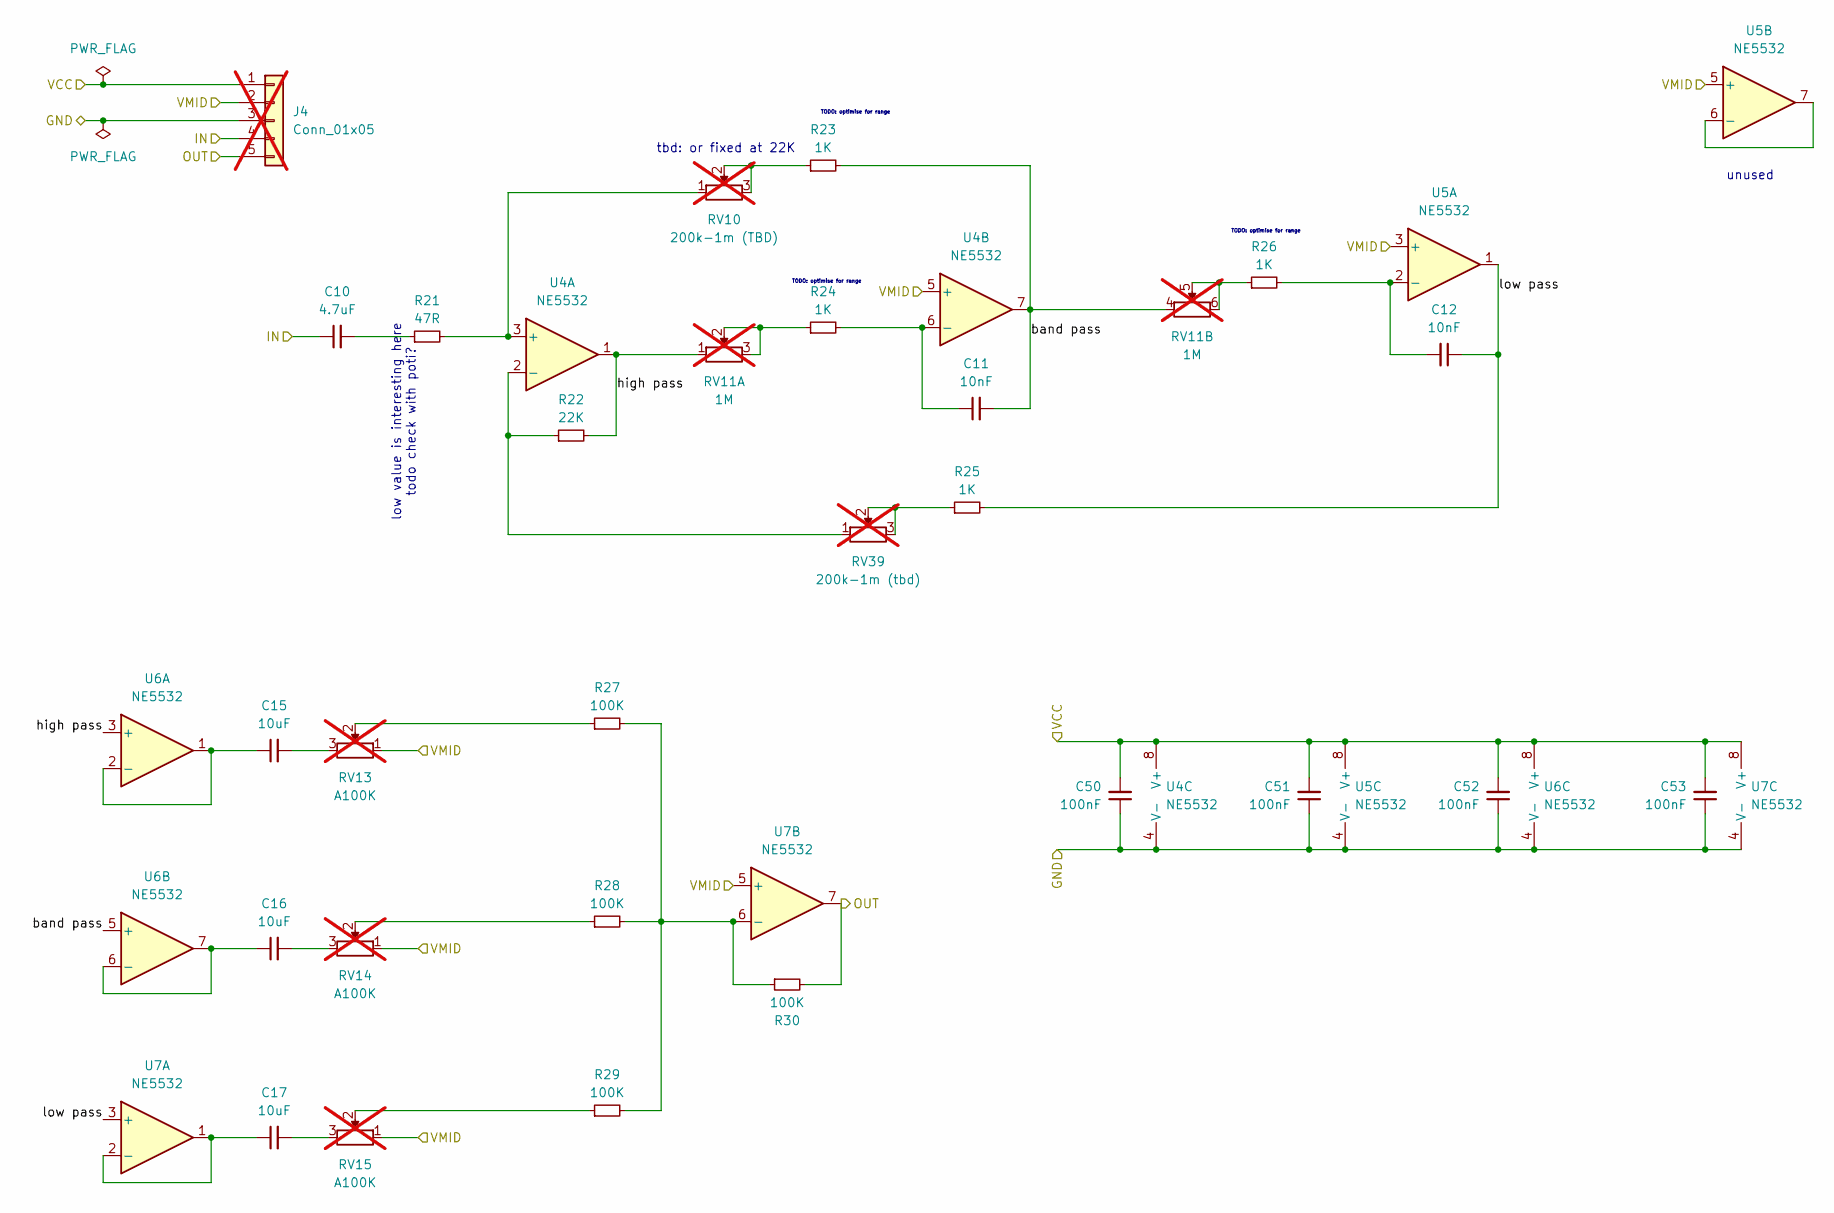
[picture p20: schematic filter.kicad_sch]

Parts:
C10: 4.7uF; C_0805_2012Metric
C11, C12: 10nF; C_0805_2012Metric
C15, C16, C17: 10uF; C_0805_2012Metric
C50, C51, C52, C53: 100nF; C_0805_2012Metric
J4: Conn_01x05; PinSocket_1x05_P2.54mm_Vertical; not fitted
R21: 47R; R_0603_1608Metric
R22: 22K; R_0603_1608Metric
R23, R24, R25, R26: 1K; R_0603_1608Metric
R27, R28, R29, R30: 100K; R_0603_1608Metric
RV10: 200k-1m (TBD); Pot_RV09AF-ALPHA; not fitted
RV11: 1M; Potentiometer_Alpha_RD902F-40-00D_Dual_Vertical; not fitted
RV13, RV14, RV15: A100K; Pot_RV09AF-ALPHA; not fitted
RV39: 200k-1m (tbd); Pot_RV09AF-ALPHA; not fitted
U4, U5, U6, U7: NE5532; SOIC-8_L4.9-W3.9-P1.27-LS6.0-BL; JLC C7426

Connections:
/Filter/GND: C50.1, C51.1, C52.1, C53.1, J4.3, U4.4 (V-), U5.4 (V-), U6.4 (V-), U7.4 (V-); also elsewhere on the board
/Filter/IN: C10.1, J4.4; also elsewhere on the board
/Filter/OUT: J4.5, R30.2, U7.7; also elsewhere on the board
/Filter/VCC: C50.2, C51.2, C52.2, C53.2, J4.1, U4.8 (V+), U5.8 (V+), U6.8 (V+), U7.8 (V+); also elsewhere on the board
/Filter/VMID: J4.2, RV13.1, RV14.1, RV15.1, U4.5 (+), U5.3 (+), U5.5 (+), U7.5 (+); also elsewhere on the board
/Filter/band pass: C11.2, R23.2, RV11.4, U4.7, U6.5 (+)
/Filter/high pass: R22.2, RV11.1, U4.1, U6.3 (+)
/Filter/low pass: C12.1, R25.2, U5.1, U7.3 (+)
unnamed: C10.2, R21.1
unnamed: C15.2, RV13.3
unnamed: C16.2, RV14.3
unnamed: C17.2, RV15.3
unnamed: R23.1, RV10.2, RV10.3
unnamed: R24.1, RV11.2, RV11.3
unnamed: R25.1, RV39.2, RV39.3
unnamed: R26.1, RV11.5, RV11.6
unnamed: R27.1, RV13.2
unnamed: R28.1, RV14.2
unnamed: R29.1, RV15.2
unnamed: R21.2, RV10.1, U4.3 (+)
unnamed: R22.1, RV39.1, U4.2 (-)
unnamed: C11.1, R24.2, U4.6 (-)
unnamed: C12.2, R26.2, U5.2 (-)
unnamed: U5.6 (-), U5.7
unnamed: C15.1, U6.1, U6.2 (-)
unnamed: C16.1, U6.6 (-), U6.7
unnamed: C17.1, U7.1, U7.2 (-)
unnamed: R27.2, R28.2, R29.2, R30.1, U7.6 (-)

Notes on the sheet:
TODO: optimise for range
unused
low value is interesting here todo check with poti?
tbd: or fixed at 22K

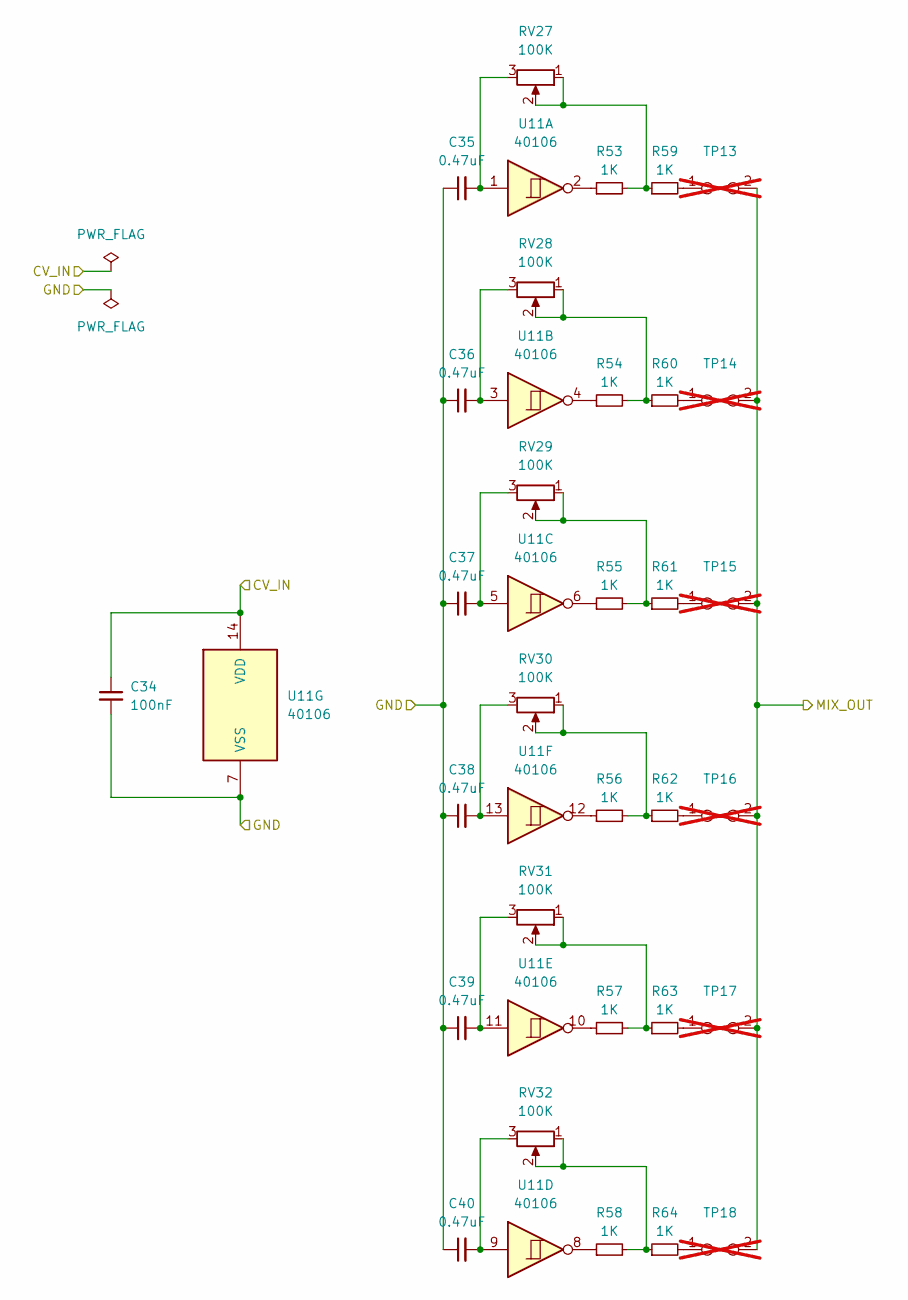
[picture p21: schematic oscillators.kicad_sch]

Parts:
C34: 100nF; C_0805_2012Metric
C35, C36, C37, C38, C39, C40: 0.47uF; C_0805_2012Metric
R53, R54, R55, R56, R57, R58, R59, R60, R61, R62, R63, R64: 1K; R_0603_1608Metric
RV27, RV28, RV29, RV30, RV31, RV32: 100K; Potentiometer_Bourns_3296W_Vertical; JLC C118963
TP13, TP14, TP15, TP16, TP17, TP18: key1; TouchPad_2Pole_Square_15x15mm; not fitted
U11: 40106; SOIC-14_L8.7-W3.9-P1.27-LS6.0-BL; JLC C38184

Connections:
/keys/CV_IN: C34.1, U11.14 (VDD); also elsewhere on the board
/keys/GND: C34.2, C35.1, C36.1, C37.1, C38.1, C39.1, C40.1, U11.7 (VSS); also elsewhere on the board
/keys/MIX_OUT: TP13.2, TP14.2, TP15.2, TP16.2, TP17.2, TP18.2; also elsewhere on the board
unnamed: C35.2, RV27.3, U11.1
unnamed: C36.2, RV28.3, U11.3
unnamed: C37.2, RV29.3, U11.5
unnamed: C38.2, RV30.3, U11.13
unnamed: C39.2, RV31.3, U11.11
unnamed: C40.2, RV32.3, U11.9
unnamed: R53.1, U11.2
unnamed: R53.2, R59.1, RV27.1, RV27.2
unnamed: R54.1, U11.4
unnamed: R54.2, R60.1, RV28.1, RV28.2
unnamed: R55.1, U11.6
unnamed: R55.2, R61.1, RV29.1, RV29.2
unnamed: R56.1, U11.12
unnamed: R56.2, R62.1, RV30.1, RV30.2
unnamed: R57.1, U11.10
unnamed: R57.2, R63.1, RV31.1, RV31.2
unnamed: R58.1, U11.8
unnamed: R58.2, R64.1, RV32.1, RV32.2
unnamed: R59.2, TP13.1
unnamed: R60.2, TP14.1
unnamed: R61.2, TP15.1
unnamed: R62.2, TP16.1
unnamed: R63.2, TP17.1
unnamed: R64.2, TP18.1

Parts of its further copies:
C1, C27, C41: 100nF; C_0805_2012Metric
C2, C3, C4, C5, C6, C26, C28, C29, C30, C31, C32, C33, C42, C43, C44, C46, C47, C48: 0.47uF; C_0805_2012Metric
R1, R2, R3, R4, R5, R6, R7, R8, R9, R10, R11, R12, R41, R42, R43, R44, R45, R46, R47, R48, R49, R50, R51, R52, R65, R66, R67, R68, R69, R70, R71, R72, R73, R74, R75, R76: 1K; R_0603_1608Metric
RV1, RV2, RV3, RV4, RV5, RV6, RV21, RV22, RV23, RV24, RV25, RV26, RV33, RV34, RV35, RV36, RV37, RV38: 100K; Potentiometer_Bourns_3296W_Vertical; JLC C118963
TP1, TP2, TP3, TP4, TP5, TP6, TP7, TP8, TP9, TP10, TP11, TP12, TP19, TP20, TP21, TP22, TP23, TP24: key1; TouchPad_2Pole_Square_15x15mm; not fitted
U1, U3, U12: 40106; SOIC-14_L8.7-W3.9-P1.27-LS6.0-BL; JLC C38184

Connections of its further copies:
/keys/CV_IN: C1.1, C27.1, C41.1, U1.14 (VDD), U3.14 (VDD), U12.14 (VDD); also elsewhere on the board
/keys/GND: C1.2, C2.1, C3.1, C4.1, C5.1, C6.1, C26.1, C27.2, C28.1, C29.1, C30.1, C31.1, C32.1, C33.1, C41.2, C42.1, C43.1, C44.1, C46.1, C47.1, C48.1, U1.7 (VSS), U3.7 (VSS), U12.7 (VSS); also elsewhere on the board
/keys/MIX_OUT: TP1.2, TP2.2, TP3.2, TP4.2, TP5.2, TP6.2, TP7.2, TP8.2, TP9.2, TP10.2, TP11.2, TP12.2, TP19.2, TP20.2, TP21.2, TP22.2, TP23.2, TP24.2; also elsewhere on the board
unnamed: C2.2, RV1.3, U1.1
unnamed: C3.2, RV2.3, U1.3
unnamed: C4.2, RV3.3, U1.5
unnamed: C5.2, RV4.3, U1.13
unnamed: C6.2, RV5.3, U1.11
unnamed: C26.2, RV6.3, U1.9
unnamed: C28.2, RV21.3, U3.1
unnamed: C29.2, RV22.3, U3.3
unnamed: C30.2, RV23.3, U3.5
unnamed: C31.2, RV24.3, U3.13
unnamed: C32.2, RV25.3, U3.11
unnamed: C33.2, RV26.3, U3.9
unnamed: C42.2, RV33.3, U12.1
unnamed: C43.2, RV34.3, U12.3
unnamed: C44.2, RV35.3, U12.5
unnamed: C46.2, RV36.3, U12.13
unnamed: C47.2, RV37.3, U12.11
unnamed: C48.2, RV38.3, U12.9
unnamed: R1.1, U1.2
unnamed: R1.2, R7.1, RV1.1, RV1.2
unnamed: R2.1, U1.4
unnamed: R2.2, R8.1, RV2.1, RV2.2
unnamed: R3.1, U1.6
unnamed: R3.2, R9.1, RV3.1, RV3.2
unnamed: R4.1, U1.12
unnamed: R5.1, U1.10
unnamed: R6.1, U1.8
unnamed: R7.2, TP1.1
unnamed: R8.2, TP2.1
unnamed: R9.2, TP3.1
unnamed: R4.2, R10.1, RV4.1, RV4.2
unnamed: R10.2, TP4.1
unnamed: R5.2, R11.1, RV5.1, RV5.2
unnamed: R11.2, TP5.1
unnamed: R6.2, R12.1, RV6.1, RV6.2
unnamed: R12.2, TP6.1
unnamed: R41.1, U3.2
unnamed: R41.2, R47.1, RV21.1, RV21.2
unnamed: R42.1, U3.4
unnamed: R42.2, R48.1, RV22.1, RV22.2
unnamed: R43.1, U3.6
unnamed: R43.2, R49.1, RV23.1, RV23.2
unnamed: R44.1, U3.12
unnamed: R44.2, R50.1, RV24.1, RV24.2
unnamed: R45.1, U3.10
unnamed: R45.2, R51.1, RV25.1, RV25.2
unnamed: R46.1, U3.8
unnamed: R46.2, R52.1, RV26.1, RV26.2
unnamed: R47.2, TP7.1
unnamed: R48.2, TP8.1
unnamed: R49.2, TP9.1
unnamed: R50.2, TP10.1
unnamed: R51.2, TP11.1
unnamed: R52.2, TP12.1
unnamed: R65.1, U12.2
unnamed: R65.2, R71.1, RV33.1, RV33.2
unnamed: R66.1, U12.4
unnamed: R66.2, R72.1, RV34.1, RV34.2
unnamed: R67.1, U12.6
unnamed: R67.2, R73.1, RV35.1, RV35.2
unnamed: R68.1, U12.12
unnamed: R68.2, R74.1, RV36.1, RV36.2
unnamed: R69.1, U12.10
unnamed: R69.2, R75.1, RV37.1, RV37.2
unnamed: R70.1, U12.8
unnamed: R70.2, R76.1, RV38.1, RV38.2
unnamed: R71.2, TP19.1
unnamed: R72.2, TP20.1
unnamed: R73.2, TP21.1
unnamed: R74.2, TP22.1
unnamed: R75.2, TP23.1
unnamed: R76.2, TP24.1

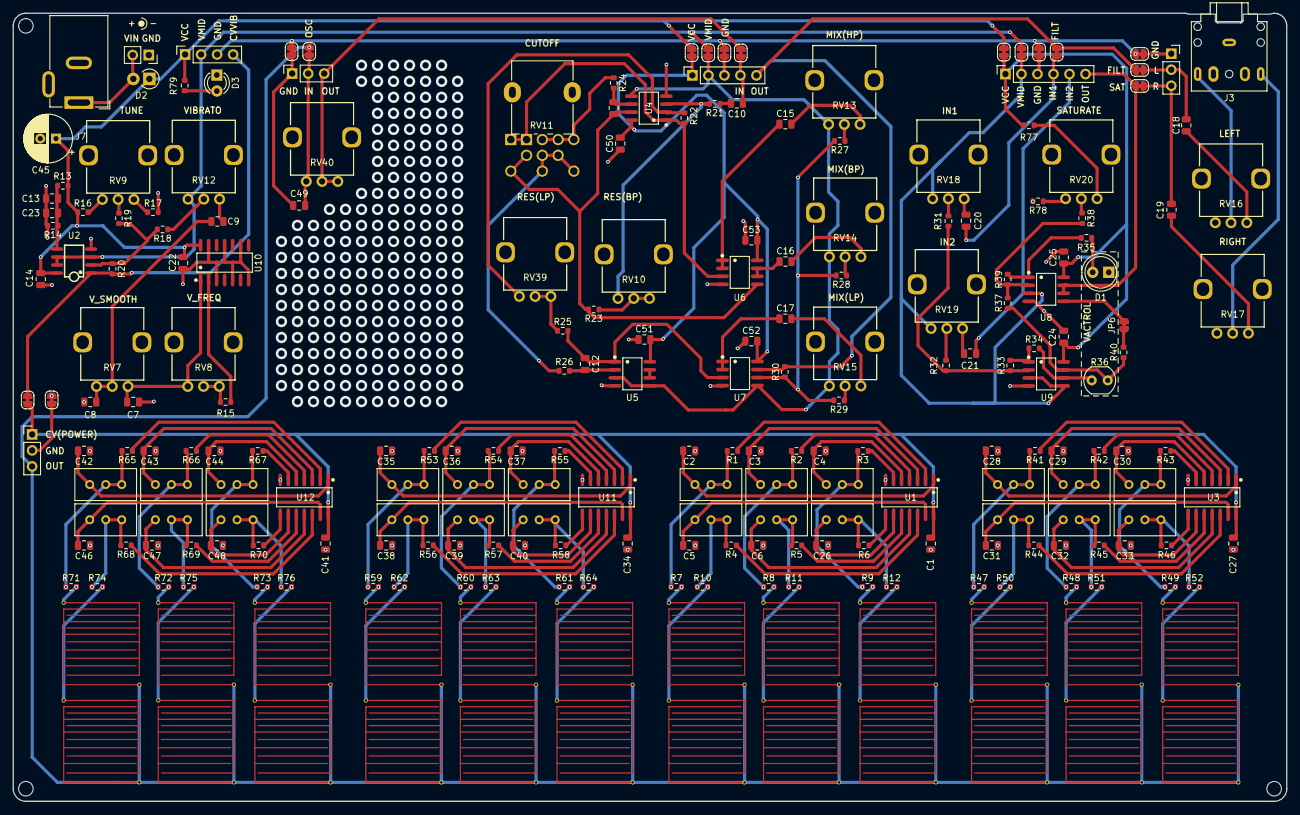
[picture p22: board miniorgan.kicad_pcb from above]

Board: 2 copper layers, 202.0 x 125.0 mm, 236 parts (0 on the bottom side), 176 nets.

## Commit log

2025-02-03 miniorgan v0
    [bom.csv, compressor.kicad_sch, designators.csv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]
2025-02-03 update footprint of dual gang potentiometer to accomodate larger poti
    [miniorgan.kicad_pcb]
2025-02-03 fix mixers in filter and compressor, update pcb
    [compressor.kicad_sch, filter.kicad_sch, miniorgan.kicad_pcb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]
2025-02-03 mark components as DNP, add LCSC part numbers
    [compressor.kicad_sch, filter.kicad_sch, keys.kicad_sch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]
2025-11-10 add local changes
    [bom.csv, compressor.kicad_sch, filter.kicad_sch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]
